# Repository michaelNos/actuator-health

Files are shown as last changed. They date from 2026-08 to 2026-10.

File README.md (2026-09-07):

# Actuator Health Monitoring System

Engineering development repository for a laboratory-scale actuator condition-monitoring system based initially on current measurement and waveform analysis of a low-voltage DC actuator.

Rev-1 is developed **design-first**: the product is specified and baselined at system and subsystem level before physical implementation begins. Implementation and verification then follow the approved engineering documentation rather than completing the design ad hoc on the bench.

## Current project status

The Rev-1 Stage A architecture, subsystem designs, verification plan, and implementation handoff are frozen. **Stage B implementation and bench validation are now in progress.**

Completed Stage B work includes:

- initial DC motor and bench-supply characterization;
- ACS724 current-sensor bring-up;
- low-current DC calibration and linearity verification;
- steady-state motor-current validation;
- oscilloscope measurement-path troubleshooting and controlled noise investigation;
- HANMATEK DOS1102S USB export workflow using BMP, BIN, and CSV;
- reproducible raw-waveform analysis from exported CSV data;
- controlled OFF/ON spectral comparison and repeatability testing;
- first speed-dependent motor-current spectral observation.

The present low-current bench calibration is:

```text
VOUT = 0.46910 + 0.74472 * I
I    = (VOUT - 0.46910) / 0.74472
```

where `VOUT` is in volts and `I` is in amperes.

At the validated 4 V operating point, the calibrated ACS724 reproduced approximately **34.8 mA** while the PSU indicated **35 mA**. This is strong bench agreement, but not a formal accuracy certification because the PSU display is not an independently calibrated current reference.

## Latest dynamic-measurement result

Controlled 1-second CH1 CSV captures were acquired at **10 kS/s** with matched oscilloscope settings. Repeated OFF/ON testing showed a low-frequency component that appears with motor operation and is not comparably present in adjacent OFF captures.

A follow-up operating-point test showed the dominant motor-related component moving with motor supply voltage / speed:

| Motor supply | PSU current | PSU power | Dominant component |
|---:|---:|---:|---:|
| 4.0 V | 34 mA | 0.135 W | ~81 Hz |
| 5.0 V | 35 mA | 0.175 W | ~108 Hz |
| 6.0 V | 36 mA | 0.216 W | ~134 Hz |

This is strong evidence that the feature is associated with the running motor rather than fixed bench interference. Its exact physical mechanism has **not** yet been assigned, and it is **not** accepted as a health or fault signature.

The broadband ACS724 output background remains much larger than the localized motor-related spectral component, so measurement-chain noise characterization remains an active Stage B task.

## Immediate next engineering work

The next controlled verification step is a **same-ground noise-floor capture** using the same oscilloscope acquisition settings as the valid ACS724 CSV measurements. This will quantify how much of the approximately 25 mV RMS-type background originates in the measurement setup itself.

The planned sensor-supply comparison then follows:

```text
bench 5 V -> Arduino 5 V -> bench 5 V
```

with the sensor, probe, grounding, and acquisition configuration held fixed as far as practical.

Only after the dominant background-noise contributors are understood will the project proceed to the designed analog-front-end / anti-alias implementation and full dynamic verification.

The formal Rev-1 diagnostic band remains **DC-10 kHz**. The current 10 kS/s scope CSV captures are suitable for the present low-frequency investigation only; they do not satisfy final full-band verification.

## Project documentation

The `docs/` directory is the authoritative engineering record. The `study/` directory contains supporting learning material, and `analysis/` contains reproducible analysis code.

Key Stage B records currently include:

- [Stage B Implementation Log](docs/15-stage-b-implementation-log.md)
- [ACS724 DC Calibration](docs/16-acs724-dc-calibration.md)
- [ACS724 Motor Validation and Noise Exploration](docs/evidence/acs724-motor-validation-and-noise-2026-09-07.md)
- [ACS724 Raw Waveform Export and Speed-Dependent Spectrum](docs/evidence/acs724-raw-waveform-and-speed-spectrum-2026-09-07.md)
- [`analysis/acs724_raw_csv_fft.py`](analysis/acs724_raw_csv_fft.py) for reproducible DOS1102S CSV analysis

Raw instrument exports are preserved under the relevant `docs/evidence/raw/` folders. Original evidence should remain unchanged; analysis must not silently alter source files.

See the [documentation index](docs/README.md) for the authoritative documentation convention and the complete Rev-1 record.

## Measurement hardware currently in use

- **Current sensor:** Pololu #4048 / ACS724LLCTR-05AU, unidirectional 0-5 A
- **Controller:** Arduino UNO R4 WiFi
- **Oscilloscope:** HANMATEK DOS1102S, 110 MHz, integrated AFG
- **Bench PSU:** Jesverty SPS-3010V
- **Multimeter:** VC830L
- **Test actuator:** low-voltage brushed DC motor used for Stage B bench validation

The stock ACS724 carrier includes a **1 nF FILTER capacitor**, corresponding to approximately **90 kHz** sensor bandwidth. No additional ACS724 FILTER capacitance has been accepted for Rev-1 at this stage.

## Development workflow

Engineering work is controlled through documentation, explicit decisions, measured evidence, and pull requests.

One engineering phase or controlled change is developed on one branch and one pull request. Only explicitly approved engineering decisions are baselined. Values that legitimately depend on hardware, calibration, or measurements remain `TBD` until evidence exists rather than being invented.

The project owner performs the final manual merge.

## Project objective

The goal is not only to measure motor current. The final system is intended to acquire trustworthy actuator-current data, extract meaningful features, detect abnormal behavior, propagate measurement validity, and support repeatable health-monitoring decisions with a documented verification trail.

## Safety scope

Rev-1 is a low-voltage laboratory prototype. Hobby development hardware, breadboards, the Pololu ACS724 carrier, and ordinary oscilloscope probes are not to be connected directly to industrial 400 V three-phase circuits. Future industrial scaling requires appropriately rated isolated sensing and industrial installation practices.

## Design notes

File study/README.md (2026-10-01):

# Study Notes

This directory is the learning notebook for the Actuator Health Monitoring System project.

It is intentionally separate from `docs/`, which remains the authoritative professional engineering record.

## LEARN-001 — Separation of engineering baseline and study notes

**Status:** Accepted

Purchased devices, ICs, relevant modules, and laboratory instruments shall be studied as they become relevant to project development.

Broader educational material shall be maintained separately from the formal engineering phase documentation.

- `docs/` contains approved requirements, design decisions, calculations, tests, results, limitations, verification evidence, and next actions that belong to the engineering baseline.
- `study/` contains deeper device theory, operating principles, datasheet interpretation, terminology, practical lessons, experiments for learning, and Anki-style review material.

Knowledge from `study/` shall enter the formal engineering documentation only when it becomes relevant to an accepted project decision, calculation, test, result, or limitation.

Study notes are therefore educational support material and are not themselves an engineering approval mechanism.

## Study workflow

When a device becomes relevant to the project, study it before relying on it in the design:

`Identify → Read primary documentation → Understand operating principle → Understand important limits/parameters → Perform useful learning experiments → Apply relevant knowledge to the engineering design`

Important terminology may be captured in compact Anki-style form:

**Front:** What is the term or engineering question?  
**Back:** Concise technically correct explanation.

Unknown values remain unknown until verified from primary documentation, calculated, or measured.

## Explain before changing the experiment

Working preference confirmed on 2026-09-13: use short, focused messages and explain each step before asking the user to perform it.

For each measurement or setting change:

1. State the question and the relevant operating principle in plain language.
2. Explain the expected result and what alternatives would mean.
3. Give one concrete action, using the exact instrument, component, pin/net, and units.
4. State what observation to report.
5. Interpret the result before choosing the next action, and document the explanation and evidence in the relevant study note.

Use the existing schematic and confirmed instrument information. Request another photograph only when it resolves a specific missing observation. Keep observed readings, calculations, predictions, and hypotheses explicitly distinguishable. Preserve corrections and mark skipped or pending tests accurately.

Keep chat explanations brief; use the study notes for the fuller explanation, primary sources, and worked examples.

## Study notes

- [`lab-measurement-and-breadboard-notes.md`](lab-measurement-and-breadboard-notes.md) — breadboard connectivity, measurement discipline, instrument cross-checking, ACS724 transfer-function fundamentals, and review questions from Stage B bench work.
- [`acs724-dc-calibration-fundamentals.md`](acs724-dc-calibration-fundamentals.md) — resistor-load design, parallel-current sharing, resistor power, ACS724 sensitivity/offset, linear regression interpretation, voltage-reference mistakes, PSU current limiting, and review questions from the first DC calibration.
- [`acs724-noise-bandwidth-and-fft.md`](acs724-noise-bandwidth-and-fft.md) — oscilloscope signal-path checks, AC/DC coupling, bandwidth/noise trade-offs, control measurements, RMS versus peak-to-peak, FFT center/span, windowing, and lessons from the first motor OFF/ON spectral comparison.

- [`oscilloscope-acquisition-and-triggering.md`](oscilloscope-acquisition-and-triggering.md) — Sample versus Average, triggering, display settings, DC versus AC measurements, and the unresolved CH1 amplitude variation after rewiring.

- [`mcp6022-pinout-and-fixture.md`](mcp6022-pinout-and-fixture.md) — physical pin orientation, all eight pin functions, supply connections, and how the two amplifiers implement the fixture.

- [`sampling-phase-spectrum-transfer-fundamentals-2026-09-18.md`](sampling-phase-spectrum-transfer-fundamentals-2026-09-18.md) — practical calculation of sample interval/rate, Nyquist and record planning, residuals, manual phase measurement, sine/cosine fitting, FFT/harmonics, dB, complex transfer phasors, FILTER corner behavior, scope channel skew, normalized frequency response, and ACS724 dynamic timing terms.

## Initial study queue

The current project hardware provides the initial learning queue. Notes should be added when each item becomes relevant rather than attempting to study everything at once.

- Allegro ACS724 / Pololu #4048 current-sensor carrier
- Arduino UNO R4 WiFi
- Renesas RA4M1 microcontroller
- MCP6022 operational amplifier
- MAX485 RS-485 modules
- MCP2551 CAN transceiver modules
- HANMATEK DOS1102S oscilloscope and function generator
- Jesverty SPS-3010V bench power supply
- relevant passive components, protection parts, wiring, connectors, and measurement techniques as they enter the design

## Relationship to engineering phases

The engineering phase workflow does not change because of this directory.

A study note may contain explanations, examples, or experiments that are useful for learning but are not yet accepted project decisions. Formal phase documents continue to baseline only explicitly approved engineering work.

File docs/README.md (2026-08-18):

# Engineering Documentation

This directory is the authoritative engineering record for the Actuator Health Monitoring System.

## Convention

Each development phase has one numbered Markdown document. Markdown is the source of truth because engineering changes remain readable and reviewable in Git diffs and pull requests. Word/PDF documents may be generated later as deliverables, but they shall not become a competing source of truth.

## DEV-001 — Design-before-implementation workflow

**Status:** Accepted

Rev-1 of the Actuator Health Monitoring System shall be fully specified and baselined at product and subsystem level before physical implementation begins.

The design stage shall establish requirements, architecture, subsystem designs, interfaces, calculations, component selections, calibration strategy, firmware/software architecture, diagnostic strategy, BOM/build information, and verification procedures.

Physical measurements and implementation-dependent results may remain `TBD` during design where they cannot legitimately be known before hardware exists.

After the Rev-1 design baseline is complete, implementation shall proceed from the documented design. Verification shall then populate the planned tests with measured results and identify any necessary deviations or redesign.

### Consequence for phase closure

A design phase does **not** require execution of future hardware tests before it can close. It must instead provide a sufficiently complete design baseline and a defined verification method so later implementation can be performed and checked against the documentation.

Detailed test steps that do not change product design should be consolidated into verification procedures rather than promoted into separate product decisions.

## Rev-1 development stages

### Stage A — Product definition and detailed design

| Phase | Topic | Status |
|---|---|---|
| 1 | System Requirements | Complete / baselined |
| 2 | System Architecture | Complete / baselined |
| 3 | ACS724 Sensor Design and Verification Plan | Design complete / baselined |
| 4 | Measurement-Chain Requirements and Error-Budget Allocation | Design complete / baselined |
| 5 | Analog Front End and Anti-Alias Filter Design | Design complete / baselined |
| 6 | ADC and Deterministic Acquisition Design | Design complete / baselined |
| 7 | MCU Firmware and Signal-Processing Architecture | Design complete / baselined |
| 8 | Diagnostics / Health-Monitoring Logic | Design complete / baselined |
| 9 | Communication Interface Design | Design complete / baselined |
| 10 | Power and Protection Design | Design complete / baselined |
| 11 | Calibration and PC/MATLAB Analysis Design | Design complete / baselined |
| 12 | System Integration, Wiring, BOM and Build Specification | Design complete / ready for PR review |
| 13 | System Verification and Acceptance Plan | Planned |
| 14 | Rev-1 Design Review and Design Freeze | Planned |

### Stage B — Implementation

| Phase | Topic | Status |
|---|---|---|
| 15 | Rev-1 Hardware / Firmware / Software Implementation | Planned after design freeze |

### Stage C — Verification and finalization

| Phase | Topic | Status |
|---|---|---|
| 16 | Subsystem Verification, Calibration and System Validation | Planned after implementation |
| 17 | Final Results, Limitations and Product Documentation | Planned after validation |

The ordering of future design phases may be refined only through an explicit engineering-documentation update; implementation shall not begin merely because an individual subsystem design is available.

## Engineering record rule

Where practical, work remains traceable as:

`Requirement → Architecture → Design → Implementation → Verification → Evidence → PASS/FAIL`

Only explicitly approved decisions are baselined. Unknown values remain `TBD` until calculated, measured, or otherwise justified.

One engineering phase normally uses one branch and one pull request. During design, product decisions are committed as approved; verification details may be consolidated when they are procedural rather than independent design choices.

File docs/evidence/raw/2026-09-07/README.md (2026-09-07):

# Raw DOS1102S evidence inventory — 2026-09-07

Original files captured during the ACS724 USB-export and motor-spectrum experiment:

## Native screenshots
- `bmp_20_002.bmp`
- `bmp_20_003.bmp`
- `bmp_20_004.bmp`

## Native BIN exports
- `data_20_001.bin`
- `data_20_002.bin`
- `data_20_003.bin`
- `data_20_004.bin`
- `data_20_005.bin`

## CSV exports
- `data_20_006.csv` — first CSV; invalid voltage scaling because scope metadata was 10X while physical probe was 1X
- `data_20_007.csv` — corrected 1X exploratory capture; motor state unknown
- `data_20_008.csv` — corrected 1X exploratory capture; motor state unknown
- `data_20_009off.csv` — controlled motor OFF
- `data_20_010on.csv` — controlled motor ON
- `data_20_011off.csv` — repeatability sequence OFF
- `data_20_012on.csv` — repeatability sequence ON
- `data_20_013off.csv` — repeatability sequence OFF
- `data_20_014on.csv` — repeatability sequence ON
- `data_20_015-4v.csv` — motor ON, 4 V, PSU 34 mA / 0.135 W
- `data_20_016-5v.csv` — motor ON, 5 V, PSU 35 mA / 0.175 W
- `data_20_017-6v.csv` — motor ON, 6 V, PSU 36 mA / 0.216 W

005 = A1 OUT, bench
006 = B1 OUT, Arduino
007 = A2 OUT, bench
008 = A1 VCC, bench
009 = B1 VCC, Arduino
010 = A2 VCC, bench
011 = VCC, bandwidth limit OFF
012 = VCC, limit OFF
013 = VCC, 20 MHz limit ON
014 = VCC, limit OFF
015 = OUT, limit 20MHz
016 = OUT, limit 20MHz
017 = OUT, limit 20MHz

The exact original files were also bundled during the documentation session as `acs724_scope_raw_2026-09-07.zip`. Binary/raw file bytes are intentionally not reconstructed from screenshots or derived analysis.

See `docs/evidence/acs724-raw-waveform-and-speed-dependent-spectrum-2026-09-07.md` for validity classification and results, and `analysis/acs724_raw_csv_fft.py` for the reproducible CSV analysis method.

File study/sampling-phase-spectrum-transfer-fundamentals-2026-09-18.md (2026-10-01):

# Sampling, phase, spectrum, transfer function, and ACS724 dynamics — study questions

**Project:** Actuator Health Monitoring System  
**Date:** 2026-09-18  
**Purpose:** Educational note answering the questions raised during Stage B ACS724 dynamic/FILTER validation.

This is a **study note**, not an engineering-baseline approval. Numerical examples from the current bench work are used to explain the concepts. Accepted engineering decisions remain in `docs/`.

The current measurement convention is:

- **CH1:** voltage across the measured reference resistor `R8 = 67 Ω`, used to calculate primary current: `I = V_CH1 / 67 Ω`.
- **CH2:** Pololu #4048 / ACS724 `OUT` voltage relative to circuit ground.
- The temporary MCP6022 fixture creates a **positive-biased periodic current** through the ACS724 primary path.
- Current dynamic work uses coherent extraction of a known excitation frequency from noisy data.

---

## 1. How can I determine Δt, sampling rate, Nyquist frequency, record duration, and captured cycles myself — before running the measurement?

The first job is **not to read Δt from a CSV after the experiment**. The goal is to plan the acquisition from the signal frequency, then use the oscilloscope itself to verify that the selected acquisition actually provides the required sample rate.

### 1.1 What Δt means

`Δt` is the time between two consecutive stored samples:

`sample n ---- Δt ---- sample n+1 ---- Δt ---- sample n+2`

Sample rate and sample interval are reciprocals:

`fs = 1 / Δt`

therefore:

`Δt = 1 / fs`

Examples:

- `fs = 25 kSa/s` → `Δt = 1/25000 = 40 µs`
- `fs = 250 kSa/s` → `Δt = 1/250000 = 4 µs`

So to determine `Δt` yourself, determine the **actual sample rate currently used by the scope**, then take its reciprocal.

### 1.1A Project-specific DOS1102S operating rule — 10K depth is fixed

For the current Actuator Health Monitoring System bench workflow, **record depth is fixed at 10K points**. The operator should not be instructed to “set Δt”. The oscilloscope screen control available before acquisition is the horizontal main timebase:

`M: ... ms/div`

From repeated CSV captures with this exact DOS1102S setup, the stored 10K record spans approximately:

`Trecord ≈ 20 × M`

where `M` is the displayed main timebase in seconds per division.

Therefore, with `N = 10000` fixed:

`Δt ≈ Trecord/N = (20 × M)/10000`

For the convenient units used on the screen:

`Δt [µs] ≈ 2 × M [ms/div]`

and equivalently:

`fs [kSa/s] ≈ 500 / M [ms/div]`

Examples established on this bench:

| DOS1102S screen setting | Fixed depth | Approx. stored Δt | Approx. sample rate |
| --- | ---: | ---: | ---: |
| `M: 20 ms/div` | 10K | `40 µs` | `25 kSa/s` |
| `M: 5 ms/div` | 10K | `10 µs` | `100 kSa/s` |
| `M: 2 ms/div` | 10K | `4 µs` | `250 kSa/s` |

This is an **empirical project-specific rule for the current DOS1102S configuration**, not a universal oscilloscope law. It comes from the actual exported records.

#### Future bench-instruction rule

For this project:

- keep **Depth = 10K** unless an explicit engineering reason is approved to change it;
- when planning a capture, give the operator the **screen setting** to use, for example `M: 2 ms/div`;
- do **not** ask the operator to “set Δt = 4 µs” because Δt is not the direct front-panel setting;
- Δt may still be calculated in the explanation, but the actionable instruction must be the DOS1102S `M: ... ms/div` setting;
- after acquisition, verify the actual CSV timestamps/sample interval as a check.

For the current 10 kHz / ~25-samples-per-cycle requirement, the bench instruction is therefore:

`Set M: 2 ms/div, Depth: 10K.`

not:

`Set Δt = 4 µs.`

### 1.2 Method A — read the current sample rate from the oscilloscope

If the scope shows the current acquisition sample rate, use that value directly.

For example, if the scope reports:

`250 kSa/s`

then:

`Δt = 1/(250000) = 4 µs`

If it reports:

`25 kSa/s`

then:

`Δt = 40 µs`

Do not confuse the instrument's advertised **maximum** sample rate with the sample rate of the current acquisition. The scope may reduce the current sample rate when a longer time window is selected.

### 1.3 Method B — use record length and the actual stored acquisition duration

If you know:

- number of stored samples `N`;
- total duration represented by those stored samples `Trecord`;

then approximately:

`Δt ≈ Trecord / N`

and:

`fs ≈ N / Trecord`

More exactly, if the first and last stored samples are both included:

`Δt = (t_last - t_first)/(N - 1)`

For acquisition planning with 10000 points, the difference between `N` and `N-1` is very small.

Example:

`N = 10000`

`Trecord = 40 ms`

then:

`Δt ≈ 0.040/10000 = 4 µs`

and:

`fs ≈ 250 kSa/s`

### 1.4 Method C — inspect adjacent stored points on the stopped scope display

If the scope allows you to show individual sample dots and zoom deeply into a stopped record:

1. stop acquisition;
2. display/zoom until individual stored points are visible;
3. use time cursors between two adjacent points;
4. the horizontal time difference is approximately `Δt`.

This is the most direct physical interpretation of sample interval.

### 1.5 Why the visible grid alone is not enough — and what we now know for this scope

A generic oscilloscope rule such as:

`Δt = (10 horizontal divisions × time/div)/record_length`

must **not** be assumed without verification. The visible grid width and the complete stored-memory span are not necessarily the same.

For this DOS1102S bench configuration, however, repeated exported 10K records have established an empirical relationship:

`Trecord ≈ 20 × M`

not `10 × M`.

Therefore, while `M` alone is not universally enough on an arbitrary oscilloscope, it **is operationally usable here because the 10K depth is fixed and the 20 × M record-span relationship has been verified from our own CSVs**.

The project workflow is now:

`signal requirement → choose required sampling quality → convert to DOS1102S M setting → acquire at fixed 10K → verify CSV Δt afterward`

The operator-facing instruction should stop at the actual screen control:

`M: ... ms/div`

### 1.6 How to choose Δt before pressing RUN

Start from the signal frequency.

If the target signal frequency is `fsig`, then its period is:

`Tsig = 1/fsig`

Choose how many samples you want per cycle. For the present phase/waveform work, approximately **20–25 or more samples per cycle** is a useful engineering target, not a universal law.

Then:

`Δt_wanted = Tsig / samples_per_cycle`

and equivalently:

`fs_target = samples_per_cycle × fsig`

#### Example: design the 10 kHz acquisition before measuring

Target:

`fsig = 10 kHz`

Signal period:

`Tsig = 1/10000 = 100 µs`

Choose:

`25 samples/cycle`

Required sample interval:

`Δt_wanted = 100 µs / 25 = 4 µs`

Required sample rate:

`fs_target = 1/4 µs = 250 kSa/s`

So before touching RUN, the target is already known:

`10 kHz → 100 µs/cycle → 4 µs/sample → 250 kSa/s → 25 samples/cycle`

Now set the oscilloscope acquisition/timebase so that the **actual current sample rate** is approximately 250 kSa/s or faster.

### 1.7 Then determine record duration and captured cycles

If the scope stores `N = 10000` points at:

`fs = 250 kSa/s`

then:

`Trecord = N/fs = 10000/250000 = 40 ms`

At 10 kHz:

`cycles = Trecord × fsig = 0.040 × 10000 = 400 cycles`

So the complete designed acquisition is:

`10 kHz signal`

`→ 100 µs period`

`→ 4 µs desired sample spacing`

`→ 250 kSa/s sample rate`

`→ 25 samples/cycle`

`→ 10000 samples`

`→ 40 ms record`

`→ 400 captured cycles`

#### Same calculation for 1 kHz

At:

`fsig = 1 kHz`

period:

`Tsig = 1 ms`

For the same 25 samples/cycle:

`Δt_wanted = 1 ms/25 = 40 µs`

`fs_target = 25 kSa/s`

With 10000 samples:

`Trecord = 10000/25000 = 0.4 s`

Captured cycles:

`0.4 × 1000 = 400`

This is why preserving 25 samples/cycle requires a sample interval ten times shorter when the signal frequency becomes ten times higher:

- 1 kHz → `Δt = 40 µs`
- 10 kHz → `Δt = 4 µs`

### 1.8 After the acquisition, verify what actually happened

After the capture, verify that the scope actually used the intended settings:

1. actual sample rate;
2. record length;
3. actual record duration;
4. resulting samples/cycle;
5. resulting captured-cycle count.

CSV timestamps can be used later as an independent verification, but they are **not required to understand or plan Δt**.

### 1.9 From Δt to Nyquist

Once `Δt` is known:

`fs = 1/Δt`

and:

`fNyquist = fs/2`

Example with `Δt = 4 µs`:

`fs = 250 kSa/s`

`fNyquist = 125 kHz`

For a 10 kHz signal, this gives:

`samples_per_cycle = 250/10 = 25`

This is comfortably above the theoretical two-samples-per-cycle Nyquist boundary and is much more suitable for waveform and phase measurements.

### 1.10 Bench calculation checklist

Before running a periodic test, write down:

1. `fsig = ?`
2. `Tsig = 1/fsig = ?`
3. desired samples/cycle = ?
4. `Δt_wanted = Tsig/samples_per_cycle = ?`
5. `fs_target = 1/Δt_wanted = ?`
6. record length `N = ?`
7. `Trecord = N/fs = ?`
8. captured cycles `= Trecord × fsig = ?`
9. Nyquist `= fs/2 = ?`
10. verify the actual `fs` on the oscilloscope before accepting the measurement.

That is the manual acquisition-design process to use even if ChatGPT does not exist.

### 1.11 How do I decide how many samples per cycle I want?

There is no single correct number. The choice depends on **what you want to learn from the waveform**.

Nyquist gives only the theoretical minimum:

`fs > 2 * fsig`

which means a little more than two samples per cycle for an ideally band-limited sinusoid. That may be enough to avoid the most basic aliasing condition, but it is **not a good engineering target** for measuring amplitude, phase, waveform shape, or harmonics.

A practical way to think about it is:

| Measurement goal | Practical starting point |
| --- | ---: |
| Detect that a periodic signal exists | about 5–10 samples/cycle |
| Reasonable amplitude estimate | about 10–20 samples/cycle |
| Amplitude and phase | about **20–25+ samples/cycle** |
| Waveform shape / distortion | about 25–50+ samples/cycle |
| Higher harmonics / fast edges | often much higher |

These are engineering guidelines, not mathematical laws.

For the present ACS724 transfer-function work we care about:

- coherent amplitude;
- relative phase;
- distortion/harmonics;
- repeatable fitting;
- enough captured cycles for noise rejection.

Therefore **25 samples/cycle** is a useful working target.

#### Example at 10 kHz

Signal period:

`Tsig = 1/10000 = 100 µs`

Choose:

`25 samples/cycle`

Then:

`Δt = 100 µs / 25 = 4 µs`

and:

`fs = 1/4 µs = 250 kSa/s`

With a 10000-point record:

`Trecord = 10000/250000 = 40 ms`

Captured cycles:

`40 ms * 10 kHz = 400 cycles`

So this one choice gives both:

- 25 samples/cycle for waveform and phase resolution;
- 400 captured cycles for coherent averaging/fitting.

#### The trade-off with fixed record memory

If record length is fixed, increasing samples per cycle increases sample rate and therefore shortens total observation time.

At 10 kHz with 10000 stored points:

**5 samples/cycle**

`fs = 50 kSa/s`

`Trecord = 200 ms`

`cycles = 2000`

This gives many cycles, but poor representation of each cycle.

**25 samples/cycle**

`fs = 250 kSa/s`

`Trecord = 40 ms`

`cycles = 400`

This is a good compromise for our amplitude/phase work.

**100 samples/cycle**

`fs = 1 MSa/s`

`Trecord = 10 ms`

`cycles = 100`

This gives excellent detail within each cycle, but a much shorter observation window.

Therefore the acquisition-design trade-off is:

`more samples/cycle ↔ shorter record`

when record memory is fixed.

The practical decision sequence is:

`measurement goal → choose samples/cycle → calculate fs → calculate Δt → calculate Trecord → check captured-cycle count`

For the current ACS724 work:

`amplitude + phase + coherent extraction → about 25 samples/cycle`

That is why 25 samples/cycle was selected for the 1 kHz and 10 kHz dynamic measurements.

---

## 2. Is residual noise equal to ACS724 OUT minus IP−? Should CH1 and CH2 be equal?

**No. This is the most important correction in this note.**

CH1 and CH2 are not two measurements of the same physical quantity.

CH1 is the voltage across R8:

`V_CH1 = I_primary * R8`

CH2 is the sensor output:

`V_CH2 ≈ VZERO + S(f) * I_primary`

where:

- `VZERO` is the ACS724 zero-current output;
- `S(f)` is its frequency-dependent sensitivity in V/A.

Therefore CH1 and CH2 should **not** normally be equal in volts.

For example, if the current variation is 7 mApp:

`V_CH1,pp = 0.007 * 67 ≈ 0.469 Vpp`

With approximately 0.8 V/A sensor sensitivity:

`V_CH2,pp ≈ 0.007 * 0.8 = 5.6 mVpp`

Those are intentionally very different voltages.

### What residual means

For CH2 we fit:

`Vfit(t) = VDC + Vtarget(t)`

Then:

`e(t) = V_CH2,measured(t) - Vfit(t)`

So residual is **CH2 minus its own modeled DC + wanted coherent component**.

It is not:

`CH2 - CH1`

The residual can contain noise, harmonics, interference, drift, quantization, and any other waveform content not included in the model.

---

## 3. What is apparent transfer? Is it power?

**Apparent transfer** means:

> The input-to-output relationship that our measurement setup appears to show, before we have proven that every part of that relationship belongs only to the ACS724 itself.

In this experiment, the **input** is the actual AC current through the ACS724 primary conductor. CH1 measures the voltage across R8, so:

`I_primary(f) = V_CH1(f) / 67 Ω`

The **output** is the coherent AC component measured at ACS724 OUT with CH2:

`V_OUT(f)`

Therefore:

`H_apparent(f) = V_OUT(f) / I_primary(f)`

Its unit is:

`V/A`

This answers the practical question:

> For every ampere of current variation at this frequency, how many volts of output variation do we observe?

Example:

`Ipp = 6.8 mA`

`V_OUT,pp = 5.8 mV`

then:

`H_apparent = 5.8 mV / 6.8 mA ≈ 0.85 V/A`

Meaning:

> At that frequency, the complete measured system appears to convert current changes into voltage changes at about 0.85 volts per ampere.

### Why it is called a transfer

A transfer function describes how an input is transferred to an output.

For our measurement:

`input = primary current`

`output = ACS724 OUT voltage`

So the transfer describes both:

- how much the amplitude changes from input to output;
- how much phase shift appears between input and output.

It is therefore more than a simple scalar gain when phase matters.

### Why we call it apparent

The measured value is not automatically the exact intrinsic sensitivity of the ACS724 itself.

The observed transfer can still contain contributions from:

- the ACS724 Hall sensing element;
- internal amplifier and compensation dynamics;
- the FILTER-pin network;
- probe/scope frequency response;
- CH1↔CH2 timing skew;
- noise;
- finite record length;
- coherent-fit uncertainty.

Conceptually:

`H_measured = H_physical_sensor+filter × H_measurement_system`

This is why the word **apparent** is useful during validation: it means “this is what the experiment currently makes us observe.”

As controls identify and remove measurement artifacts, the estimate can move closer to the physical sensor/filter transfer.

### Example from the current project

At 10 kHz, the raw measured phase was about:

`-74°`

The same-node control showed that approximately:

`-14.5°`

came from a one-sample CH1↔CH2 acquisition/export offset.

Therefore the original `-74°` phase was an **apparent phase transfer** of the complete measured chain, not purely the ACS724.

After correcting the known timing artifact, the estimate moved closer to the physical response:

`≈ -60°`

This does **not** prove that every remaining degree of phase lag belongs only to the bare ACS724; the physical sensor, FILTER network, and any remaining measurement-chain dynamics still contribute.

### Apparent transfer is not power

No power quantity is being calculated here.

Power would have units such as watts:

`W = V × A`

Our transfer has units:

`V/A`

So this is a frequency-dependent sensitivity/gain, not electrical power.

### Magnitude and phase form

For frequency-domain work, transfer is often written as a complex phasor:

`H(f) = |H(f)| ∠ φ(f)`

For example:

`H(1 kHz) ≈ 0.85 ∠ -18° V/A`

means:

- the measured magnitude is about `0.85 V/A`;
- the output sinusoid lags the current-reference sinusoid by about `18°`.

So the most useful summary is:

`transfer = input-output relationship`

`apparent transfer = the input-output relationship currently observed by the complete experiment`

That distinction is important until the measurement chain has been fully characterized.

---

## 4. How can I determine phase without ChatGPT?

For two clean periodic signals of the same frequency, use the oscilloscope's time cursors.

1. Measure the period `T`.
2. Choose corresponding points on CH1 and CH2, preferably rising zero crossings or equivalent peaks.
3. Measure their time displacement `Δt_phase`.
4. Convert to phase:

   `phase_deg = 360° * Δt_phase / T`

If CH2 occurs later than CH1, CH2 **lags**, so with our convention its phase is negative.

Example at 10 kHz:

`T = 1/10000 = 100 µs`

If CH2 occurs 16 µs after CH1:

`φ = -360 * 16/100 = -57.6°`

For noisy CH2, a single cursor crossing can be inaccurate. The coherent sine/cosine fit uses all samples and is therefore more robust, but the cursor method is the direct manual method.

The DOS1102S specification also lists automatic `Phase A→B` and delay measurements, but any automatic result should be checked against known controls when millivolt-level noisy signals are involved.

---

## 5. At 1 kHz or 10 kHz, are we sending AC current? Why does current change faster or slower?

The AFG generates a periodic voltage, normally a sine.

In our temporary fixture the MCP6022 shifts it so the current through the ACS724 remains **positive**. Therefore the current is best described as:

`i(t) = IDC + IAC*sin(2πft + φ)`

So it contains:

- a DC bias;
- an AC variation/ripple.

It is **not** a bipolar current that necessarily reverses direction every half-cycle.

Frequency tells us how fast the repeating change happens:

- 100 Hz → period = 10 ms
- 1 kHz → period = 1 ms
- 10 kHz → period = 100 µs

At 10 kHz the current completes 10000 oscillations each second. At 100 Hz it completes only 100.

The current changes because the driving voltage changes. In the temporary mostly resistive primary path, current follows the drive relatively quickly. In a strongly inductive load, inductance would oppose rapid current change according to `V = L di/dt`.

Also, this is not an **impulse**. An impulse is a short transient event. We are applying a periodic sinusoidal stimulus.

---

## 6. How can I calculate spectrum and harmonics manually on paper?

If you want to calculate the spectrum yourself from measured samples, without using the oscilloscope FFT function, you are doing a small **DFT/Fourier calculation by hand**.

For this project you usually do not need to calculate the entire spectrum. If the AFG is set to `1 kHz`, you can calculate selected components directly:

`1 kHz, 2 kHz, 3 kHz, 4 kHz, ...`

one harmonic at a time.

### 6.1 Start with measured samples

Suppose you have `N` equally spaced samples:

`x0, x1, x2, ..., x(N-1)`

with sample interval:

`Δt`

Sample `n` occurred at:

`tn = n * Δt`

First calculate the DC/mean value:

`VDC = (1/N) * Σ x_n`

Then remove it:

`y_n = x_n - VDC`

Now `y_n` contains only the varying part of the waveform.

### 6.2 Ask whether the waveform contains a chosen frequency

Choose a frequency `f`.

For every sample calculate:

`θ_n = 2π f t_n`

Then calculate the sine projection:

`S_f = (2/N) * Σ [y_n * sin(θ_n)]`

and the cosine projection:

`C_f = (2/N) * Σ [y_n * cos(θ_n)]`

These two sums answer:

> How much of the measured waveform points in the sine direction and how much points in the cosine direction at frequency f?

From them calculate the peak amplitude:

`A_pk = sqrt(S_f^2 + C_f^2)`

and peak-to-peak amplitude:

`A_pp = 2 * A_pk`

Using the phase convention adopted in this project:

`φ = atan2(C_f, S_f)`

This is the hand-calculation equivalent of extracting one Fourier component.

### 6.3 Small paper example

Take eight equally spaced samples of one ideal sine period:

| n | angle | measured x_n |
| ---: | ---: | ---: |
| 0 | 0° | 0 |
| 1 | 45° | 0.707 |
| 2 | 90° | 1 |
| 3 | 135° | 0.707 |
| 4 | 180° | 0 |
| 5 | 225° | -0.707 |
| 6 | 270° | -1 |
| 7 | 315° | -0.707 |

The mean is:

`VDC = 0`

For the fundamental, multiply every measured sample by the sine at the same angle:

`x_n * sin(θ_n)`

The products are approximately:

`0, 0.5, 1, 0.5, 0, 0.5, 1, 0.5`

Sum:

`Σ x_n sin(θ_n) = 4`

Therefore:

`S_1 = (2/8) * 4 = 1`

Now do the cosine projection:

`C_1 = (2/8) * Σ [x_n cos(θ_n)]`

For this ideal sine the positive and negative cosine contributions cancel:

`C_1 = 0`

Therefore:

`A_pk = sqrt(1^2 + 0^2) = 1`

and:

`A_pp = 2 V`

Phase:

`φ = atan2(0,1) = 0°`

So the manual calculation reconstructs the original sine:

`1 Vpk, 2 Vpp, 0°`

### 6.4 Calculate a harmonic using the same samples

To calculate the third harmonic, use the **same measured samples**, but test frequency:

`f = 3 f0`

Then:

`S_3 = (2/N) * Σ [y_n sin(2π * 3f0 * t_n)]`

`C_3 = (2/N) * Σ [y_n cos(2π * 3f0 * t_n)]`

and:

`A_3,pk = sqrt(S_3^2 + C_3^2)`

For the ideal sine above, those terms cancel, so:

`A_3 ≈ 0`

because the waveform contains no third harmonic.

If a measured distorted waveform gave:

`A_1 = 1.00 V`

`A_2 = 0.02 V`

`A_3 = 0.10 V`

`A_4 = 0.01 V`

then the waveform would contain a strong fundamental and a noticeable third harmonic.

### 6.5 How this becomes a spectrum

Repeat the same calculation at many frequencies.

For harmonics:

`f1 = f0`

`f2 = 2f0`

`f3 = 3f0`

and so on.

Then plot:

- horizontal axis = frequency;
- vertical axis = calculated amplitude.

That plotted set of amplitudes is the spectrum.

### 6.6 Frequency bins

For a full DFT, the natural bin spacing is:

`Δf = fs/N`

Because:

`Trecord = N/fs`

we can also write:

`Δf = 1/Trecord`

Example:

`Trecord = 40 ms`

then:

`Δf = 1/0.040 = 25 Hz`

So the DFT bins occur at:

`0, 25, 50, 75, ... Hz`

A 10 kHz component corresponds to:

`k = 10000/25 = 400`

So the 10 kHz spectral component asks:

> How strongly do the measured samples correlate with a 10 kHz sine and a 10 kHz cosine?

### 6.7 The physical idea behind the calculation

For each frequency of interest:

1. generate the corresponding sine values;
2. multiply the measured waveform by those sine values and sum;
3. generate the corresponding cosine values;
4. multiply the measured waveform by those cosine values and sum;
5. combine the two results into magnitude and phase.

If the products mostly cancel:

`little component at that frequency`

If they reinforce:

`strong component at that frequency`

The FFT performs essentially this Fourier decomposition very efficiently for many frequencies at once.

For learning on paper, do **not** start with 10000 samples. Use perhaps 8 or 16 samples of a simple waveform and calculate:

- DC;
- fundamental;
- second harmonic;
- third harmonic.

Once those calculations are clear, the FFT is no longer a black box.

---

## 7. If the fundamental is highest and harmonics are much smaller, is the fundamental the wanted result and the rest just noise?

For the present **transfer measurement at a commanded frequency**, the fundamental is the main wanted component.

But harmonics are **not automatically noise**.

A harmonic is a deterministic component at an integer multiple of the fundamental. It can be caused by:

- waveform distortion;
- nonlinearity;
- clipping;
- asymmetry;
- the stimulus generator/fixture;
- the sensor or other circuitry.

Random/broadband noise is different: it is not locked to exact integer multiples in the same deterministic way.

So:

- for `H(1 kHz)`, use the coherent 1 kHz component;
- do not add 3 kHz or 5 kHz into the 1 kHz gain;
- but keep harmonics as diagnostic information because they can reveal distortion or later become health-monitoring features.

The third harmonic in CH1 during our tests was therefore **unmodeled residual content**, but not necessarily random noise.

---

## 8. Why does filtering increase phase lag?

Consider a first-order RC low-pass:

`H(jω) = 1 / (1 + jωRC)`

Its phase is:

`φ = -atan(ωRC)`

A capacitor must charge and discharge. It cannot reproduce rapid input changes instantaneously. As frequency increases, the output waveform increasingly trails the input waveform.

At very low frequency:

`ωRC << 1 → φ ≈ 0°`

At the corner frequency:

`ωRC = 1 → φ = -45°`

Far above the corner:

`ωRC >> 1 → φ approaches -90°`

The lag is not an arbitrary penalty added by mathematics; it is the time-domain consequence of energy storage in the capacitor.

---

## 9. What does “close to Nyquist” mean?

For sample rate `fs`, Nyquist frequency is:

`fN = fs/2`

A sinusoid at Nyquist has only two samples per cycle in the ideal limiting case.

Our old 10 kHz acquisition used:

`fs = 25 kSa/s`

Therefore:

`fN = 12.5 kHz`

and:

`samples_per_cycle = 25/10 = 2.5`

So 10 kHz was very close to the theoretical sampling limit.

It was technically below Nyquist, but there was very little margin. Harmonics above 12.5 kHz could alias into lower frequencies, and waveform/phase interpretation became fragile.

After changing acquisition:

`fs = 250 kSa/s`

At 10 kHz:

`samples_per_cycle = 25`

and Nyquist is 125 kHz. That is much healthier for quantitative work.

Nyquist is a mathematical minimum for reconstructing an ideally band-limited signal, **not a recommendation to measure real analog waveforms with only two or three points per cycle**.

---

## 10. Are we measuring OUT and IP− to calculate residual noise?

No.

We measure them simultaneously for two different purposes:

- CH1 at IP−/R8 gives the primary-current reference.
- CH2 at ACS724 OUT gives the sensor response.

We calculate the transfer:

`H(f) = V_CH2(f) / (V_CH1(f)/R8)`

Residual is calculated separately from one channel after fitting its model.

For CH2:

`e_CH2(t) = V_CH2(t) - [VDC + fitted_target_sine(t)]`

For CH1 we can calculate a separate CH1 residual in the same way.

CH1 is not subtracted from CH2 to obtain noise.

---

## 11. How can I determine VDC manually from an AC-varying signal?

If the scope uses DC coupling, the simplest definition is the time average:

`VDC = (1/N) * Σ v[n]`

On the scope, use a **Mean/Average** voltage measurement if available.

For a clean symmetric sine with no distortion:

`VDC ≈ (Vmax + Vmin)/2`

Example:

`Vmax = 0.506 V`

`Vmin = 0.494 V`

then:

`VDC ≈ 0.500 V`

For a distorted/noisy waveform, the arithmetic mean over many complete cycles is better than midpoint-of-extremes because Vmax and Vmin are sensitive to noise spikes.

---

## 12. How do I understand sine and cosine from the AFG?

The AFG normally generates **one sinusoid**. We are not physically generating a separate sine and cosine.

Mathematically:

`sin(ωt)`

and:

`cos(ωt)`

have the same shape and frequency; cosine is simply sine shifted by 90°:

`cos(ωt) = sin(ωt + 90°)`

Our analysis writes:

`A sin(ωt) + B cos(ωt)`

because that combination can represent a sine of **any phase**:

`C sin(ωt + φ)`

with:

`C = sqrt(A² + B²)`

`φ = atan2(B,A)`

The sine/cosine pair is therefore an analysis coordinate system. The AFG still generates one periodic waveform.

---

## 13. What does −0.49 dB represent?

The earlier `-0.49 dB` number represented an **amplitude ratio**, not absolute voltage and not directly power.

For amplitudes:

`dB = 20 log10(A2/A1)`

A value of `-0.49 dB` corresponds to:

`A2/A1 = 10^(-0.49/20) ≈ 0.945`

So the second amplitude is about **94.5%** of the reference amplitude: approximately 5.5% lower.

Negative dB means attenuation relative to the chosen reference.

That `-0.49 dB` was from the first 10 kHz result compared with the 1 kHz estimate. It was **not the final multi-run estimate**. The later complex-average comparison gave approximately `-0.70 dB`.

---

## 14. What is a complex transfer phasor?

At one frequency, a sinusoid can be represented by:

- magnitude;
- phase.

A phasor stores both together.

For the transfer:

`H(f) = Vout_phasor / Iin_phasor`

It can be written as:

`H = a + jb`

or:

`H = |H| ∠ φ`

Example:

`H(10 kHz) ≈ 0.784 ∠ -59.9° V/A`

means:

- magnitude: about 0.784 V/A;
- output lags the current reference by about 59.9° under the corrected measurement convention.

Complex averaging is useful because it averages the in-phase and quadrature information together. Simply averaging magnitudes would ignore whether individual estimates point in different phase directions.

---

## 15. Does the ACS724 FILTER allow only signals below 15.5 kHz to pass?

No.

The approximately 15.5 kHz value was our estimated **corner frequency** for the FILTER-pin RC network using:

`RF ≈ 1.8 kΩ`

and total capacitance approximately:

`C ≈ 1 nF + 4.7 nF = 5.7 nF`

Then:

`fc = 1/(2πRFC) ≈ 15.5 kHz`

A low-pass filter is not a brick wall.

At `fc` a first-order low-pass has magnitude:

`1/sqrt(2) ≈ 0.707`

which is `-3.01 dB`.

Signals above `fc` still pass, but with progressively greater attenuation and phase lag. Far above `fc`, a first-order pole approaches a -20 dB/decade magnitude slope.

Also, 15.5 kHz is not the ACS724's entire internal bandwidth. It is an estimate for the external FILTER capacitor acting with the device's internal FILTER resistance. Allegro specifies the unfiltered ACS724 analog bandwidth around 120 kHz and provides the FILTER pin so the user can trade bandwidth for lower noise.

---

## 16. If CH1 and CH2 measure the same node, can phase still be different? Why?

Electrically, if both probes measure exactly the same physical node relative to the same ground at the same time, the true phase difference should be approximately:

`0°`

So if CH1 and CH2 are on the same node, a measured phase difference is not expected to come from the circuit itself.

### Why does a “sample” exist at all?

A digital oscilloscope does not store a perfectly continuous waveform.

Instead, it measures voltage at discrete instants and stores a sequence such as:

`V[0], V[1], V[2], V[3], ...`

The time between neighboring stored points is the sample interval:

`Δt`

For example, if:

`Δt = 4 µs`

then the stored waveform corresponds conceptually to measurements at:

`0 µs, 4 µs, 8 µs, 12 µs, ...`

That is what one **sample step** means.

### What did the same-node control reveal?

In our same-node experiment, both probes were physically connected to the same R8 signal node, so the electrical phase difference should have been approximately zero.

But the exported waveforms behaved approximately like:

`CH1[n] ≈ CH2[n+1]`

rather than:

`CH1[n] ≈ CH2[n]`

So CH2 appeared delayed by approximately **one stored sample** relative to CH1.

At 10 kHz:

`Δt = 4 µs`

and one signal period is:

`T = 100 µs`

Therefore one sample corresponds to:

`360° * 4/100 = 14.4°`

At 1 kHz:

`Δt = 40 µs`

and:

`T = 1 ms`

so again:

`360° * 40/1000 = 14.4°`

This matched the approximately `-14.5°` apparent phase difference observed in the same-node controls.

When CH2 was advanced by one stored sample in analysis, the same-node phase difference fell to approximately zero.

### Does this mean the circuit created an extra sample?

No.

The “extra sample” is not a physical electrical event in the ACS724 circuit.

It is an observed timing/alignment difference between how the two channels appeared in the stored/exported digital data.

### Why does this one-sample offset exist?

The exact internal cause is **not established**.

Possible mechanisms in a digital oscilloscope can include:

- channels being digitized or processed sequentially rather than perfectly simultaneously;
- channel-specific ADC or digital-pipeline delay;
- memory alignment;
- export/CSV alignment;
- firmware processing.

However, none of those mechanisms has been proven for this DOS1102S.

The accepted experimental statement is therefore only:

> When both probes measured the same physical signal, the exported CH2 waveform appeared approximately one stored sample behind CH1.

Do not replace that measured fact with an invented internal explanation.

### What this means for future phase measurements

For same-node measurements:

`true electrical phase ≈ 0°`

For CH1-on-R8 and CH2-on-ACS-OUT measurements, additional phase can be physically real because the ACS724 and its filtering have dynamics.

Therefore:

- a same-node phase difference is evidence of measurement-chain timing skew;
- a current-reference-to-sensor-output phase difference can contain both measurement-chain skew and real sensor/filter dynamics.

The same-node control lets us estimate and correct the known channel-alignment artifact before interpreting the physical phase response.

---

## 17. What does H(10k)/H(1k) tell us? What does a ratio generally tell us?

A ratio compares one quantity with another reference.

If:

`R = A2/A1`

then:

- `R = 1`: equal;
- `R < 1`: A2 is smaller;
- `R > 1`: A2 is larger.

For frequency response, use the **complex ratio**:

`Hnorm = H(10 kHz) / H(1 kHz)`

Magnitude:

`|Hnorm| = |H10| / |H1|`

Phase:

`φnorm = φ10 - φ1`

Using the corrected current estimates:

`|H1| ≈ 0.850 V/A`

`|H10| ≈ 0.784 V/A`

Therefore:

`|H10/H1| = 0.784/0.850 ≈ 0.922`

In dB:

`20 log10(0.922) ≈ -0.70 dB`

With phases approximately:

`φ1 = -18.18°`

`φ10 = -59.87°`

then:

`Δφ = -59.87 - (-18.18) ≈ -41.69°`

This normalized ratio is useful because constant absolute sensitivity factors largely cancel. It tells us **how the system changes with frequency**, which is what a frequency-response measurement is meant to show.

---

## 18. How are propagation delay, response time, and rise time calculated?

These are normally **measured from a step response**, not derived from one universal formula.

According to the ACS724 datasheet definitions:

### Propagation delay, tpd

Measure the time between:

- input current reaching 20% of its final step value;
- sensor output reaching 20% of its corresponding final change.

`tpd = t(output 20%) - t(input 20%)`

### Response time, tRESPONSE

Measure the time between:

- input current reaching 90% of its final value;
- sensor output reaching 90% of its corresponding final value.

`tRESPONSE = t(output 90%) - t(input 90%)`

### Rise time, tr

This belongs to the output waveform itself:

`tr = t(output 90%) - t(output 10%)`

For a simple first-order system:

`tr(10–90%) ≈ 2.197τ`

and approximately:

`fc ≈ 0.35/tr`

But the actual ACS724 is more complex than one ideal RC pole, so use datasheet definitions or measured step data for the real device.

Do not confuse these three quantities:

- propagation delay asks **when the output starts following relative to the input**;
- rise time asks **how long the output takes to travel from 10% to 90%**;
- response time compares the input's 90% time with the output's 90% time.

Primary source: Allegro ACS724 datasheet, section “Response Characteristics Definitions and Performance Data”.

---

## 19. Why does RC = f/fc?

It does **not**.

The correct dimensionless expression is:

`ωRC = f/fc`

Derivation:

`fc = 1/(2πRC)`

and:

`ω = 2πf`

Therefore:

`ωRC = (2πf)RC`

From the corner-frequency equation:

`2πRC = 1/fc`

so:

`ωRC = f/fc`

This matters because:

- `RC` has units of seconds;
- `f/fc` has no units.

They cannot be equal by themselves.

The low-pass magnitude can therefore be written either as:

`|H| = 1/sqrt(1+(ωRC)²)`

or:

`|H| = 1/sqrt(1+(f/fc)²)`

and phase as:

`φ = -atan(ωRC) = -atan(f/fc)`

---

## 20. Why does delay contribute to phase shift?

A time delay means the output waveform is shifted to the right in time:

`y(t) = x(t - td)`

For a sine:

`x(t) = sin(2πft)`

then:

`y(t) = sin[2πf(t-td)]`

Expand:

`y(t) = sin(2πft - 2πf td)`

So the phase shift caused by pure delay is:

`φ = -2πf td` radians

or:

`φ = -360° * f * td`

This explains why the same physical delay creates more phase shift at higher frequency.

Example for `td = 2 µs`:

At 1 kHz:

`φ = -360 * 1000 * 2e-6 = -0.72°`

At 10 kHz:

`φ = -7.2°`

The time delay stayed 2 µs, but the 10 kHz period is ten times shorter, so 2 µs occupies ten times more of one cycle.

This is why sensor propagation delay, filter dynamics, probe/channel skew, and digital sample offset all matter in phase measurements.

---

## Compact self-check

Before any future frequency-response capture, be able to answer these without software assistance:

1. What is the target signal frequency and period?
2. What sample rate will the selected acquisition produce?
3. How many samples per cycle will that give?
4. What is Nyquist frequency?
5. How long is the record?
6. How many cycles will be captured?
7. Which node represents current and which represents sensor output?
8. What gain unit should the transfer have?
9. Is a measured phase difference physical or could it be channel timing skew?
10. Is a spectral line a harmonic, interference component, or broadband noise?

If those ten questions are clear before the capture, the measurement is much easier to interpret correctly afterward.

## Primary references

- Allegro MicroSystems, **ACS724 datasheet**: https://www.allegromicro.com/-/media/files/datasheets/acs724-datasheet.ashx
- Pololu, **ACS724 Current Sensor Carrier -5A to +5A, 5V (item #4048)**: https://www.pololu.com/product/4048
- HANMATEK, **DOS1102S product/manual center**: https://hanmatek.com/en-eu/pages/manuals-center
- Related project notes:
  - [Oscilloscope acquisition and triggering](oscilloscope-acquisition-and-triggering.md)
  - [Signal-analysis concepts used in ACS724 dynamic validation](signal-analysis-concepts-for-acs724-dynamic-validation-2026-09-11.md)
  - [ACS724 noise, bandwidth, and FFT](acs724-noise-bandwidth-and-fft.md)

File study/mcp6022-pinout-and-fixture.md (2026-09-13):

# MCP6022 Pinout and Its Role in the Fixture

Actuator Health Monitoring System — study note, 2026-09-13.

The breadboard device is the **8-pin PDIP MCP6022**. It contains two operational amplifiers, A and B, which share the same supply connections.

## Find pin 1 on the physical device

Look down at the marked top of the package. Orient the semicircular notch toward the top of the diagram. Pin 1 is at the upper left; a pin-1 dot, when present, is beside that corner. Count counterclockwise: **1–4 down the left side, then 5–8 up the right side**. Use the notch or pin-1 indicator to establish orientation.

MCP6022 PDIP top view: left pins 1, 2, 3, 4; right pins 8, 7, 6, 5; notch at top

This is a top view. Rotating the chip rotates this map; the electrical pin numbers stay fixed.

Pin identities and package orientation are checked against Microchip's package diagram and Table 3-1. [MCP6022 family datasheet, pages 1 and 15](https://ww1.microchip.com/downloads/en/DeviceDoc/20001685E.pdf)

## Every pin, and our connection

| Pin | Datasheet name | Meaning | Connection in our fixture |
| --- | --- | --- | --- |
| 1 | VOUTA | Amplifier A output | `VDRV`: drives R5 and connects to feedback resistor R7 |
| 2 | VINA− | A inverting input | Junction of R6 (`RIN`) and R7 (`RF`) |
| 3 | VINA+ | A non-inverting input | `VREF_BUF`, supplied by pin 7 |
| 4 | VSS | Lower supply rail | PSU GND |
| 5 | VINB+ | B non-inverting input | `VREF_RAW`, junction of divider resistors R3 and R4 |
| 6 | VINB− | B inverting input | Connected directly to pin 7 for buffer feedback |
| 7 | VOUTB | Amplifier B output | `VREF_BUF`: connects to pins 6 and 3 |
| 8 | VDD | Upper supply rail | PSU +5 V |

The last column is derived from the [project schematic](../Schematics/actuator-health/actuator-health.kicad_sch). Pin 7 becomes our reference output because of the external wiring.

## What + and − mean on an amplifier

The input signs describe how a voltage difference influences the output. For amplifier A, increasing pin 3 relative to pin 2 pushes the output upward; increasing pin 2 relative to pin 3 pushes it downward. The same relationship applies to B's pins 5 and 6.

These are analog voltage inputs. The minus sign does not mean “connect this input to ground” or require a negative voltage.

A useful simplified model is:

`Vout = Aopen-loop × (V+ − V−)`

The open-loop gain is large. With suitable negative feedback and operation within the amplifier's limits, a small input difference makes the output settle. This is why we often calculate using **V− ≈ V+**. Feedback creates this approximate equality; the two input pins are not internally shorted.

## Amplifier B: why pins 6 and 7 are joined

R1–R4 form the reference divider. With four equal resistors and a 5 V supply:

`VREF_RAW = 5 V × R4 / (R1 + R2 + R3 + R4) = 1.25 V`

Pin 5 senses this voltage. Pin 6 senses the output because it is connected to pin 7.

If pin 7 is too low, pin 5 is above pin 6 and the amplifier drives pin 7 upward. If pin 7 is too high, feedback drives it downward. It settles near the reference voltage.

The divider supplies very little input current to pin 5. The buffer supplies its connected load from the IC's power rails, keeping loading of the divider small.

Ideally:

`pin 5 ≈ pin 6 = pin 7 ≈ 1.25 V`

Pins 6 and 7 are equal because of their wire connection. The approximate equality to pin 5 depends on correct powered operation and feedback.

## Amplifier A: why pin 2 receives two resistors

Pin 3 sets the reference at `VREF_BUF`. R6 carries the generator input toward pin 2; R7 feeds the output back to that junction.

Using negligible input current and `V(pin 2) ≈ VREF_BUF`, Kirchhoff's current law gives:

`(AFG_IN − VREF_BUF)/R6 + (VDRV − VREF_BUF)/R7 ≈ 0`

Rearranging:

`VDRV ≈ (1 + R7/R6) × VREF_BUF − (R7/R6) × AFG_IN`

For equal R6 and R7:

`VDRV ≈ 2 × VREF_BUF − AFG_IN ≈ 2.5 V − AFG_IN`

An increase at the generator input causes a decrease at pin 1. This approximation applies while the amplifier can supply the required output voltage and current.

Pin 1 drives the series path through R5, Pololu IP+ to IP−, and R8 to ground. Scope CH1 measures the voltage across R8; scope CH2 measures the separate Pololu OUT signal. Scope channel numbers do not identify the MCP6022's internal amplifiers.

## Supply pins and the capacitor

In our single-supply circuit, **pin 8 = +5 V and pin 4 = GND**. VSS denotes the lower supply rail; here it is 0 V. The specified operating supply difference is 2.5–5.5 V. [Microchip datasheet, section 3.5](https://ww1.microchip.com/downloads/en/DeviceDoc/20001685E.pdf)

C1, 100 nF, connects the pin-8 supply node to the pin-4 ground node. Its short local connections let it supply brief current changes and reduce rapid disturbance of the IC's supply. It sits across the rails, while pin 8 also has its direct supply wire. [Microchip supply bypass guidance, section 4.7](https://ww1.microchip.com/downloads/en/DeviceDoc/20001685E.pdf)

The earlier missing pin-8 supply connection and missing divider supply connection were different faults. Powering the IC enables the amplifiers; powering the divider establishes the reference they use.

## Why KiCad shows U1A, U1B, and U1C

These symbols describe **one physical chip**:

| KiCad unit | Physical pins | Role here |
| --- | --- | --- |
| U1A | 1, 2, 3 | Biased inverting driver |
| U1B | 5, 6, 7 | Reference buffer |
| U1C | 8, 4 | Shared power connections |

U1C is the supply symbol, so the drawing still represents two amplifiers and eight physical pins.

The `VREF_RAW` and `VREF_BUF` names belong to our external circuit. The MCP6022 has no dedicated VREF pin; the family datasheet also describes other devices that do. [Microchip datasheet, Table 3-1](https://ww1.microchip.com/downloads/en/DeviceDoc/20001685E.pdf)

## Match the package to the breadboard

With power disconnected when repositioning the IC, place the package across the breadboard's center trench. Its two rows of legs belong on opposite sides of the trench, and successive pins on each side occupy different numbered rows. Breadboard row numbers are not IC pin numbers.

For voltage measurements, name both points explicitly, for example **“MCP6022 pin 7 relative to circuit GND.”** Record the instrument and whether the quantity is DC, RMS, or peak-to-peak.

Continue with [oscilloscope acquisition and triggering](oscilloscope-acquisition-and-triggering.md) to understand how those voltages become waveform records.

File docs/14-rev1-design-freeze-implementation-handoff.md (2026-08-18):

# Phase 14 — Rev-1 Design Freeze and Implementation Handoff

**Status:** Design complete / ready for PR review  
**Project:** Actuator Health Monitoring System

## Purpose

Phase 14 closes Stage A design work by freezing the accepted Rev-1 product baseline and defining the controlled handoff into implementation, calibration and physical verification.

This phase does not redesign accepted subsystems and does not claim that the physical prototype has passed verification. Its purpose is to establish exactly what is frozen, what remains an implementation choice, which measured TBDs must be resolved during Stage B/C, and how changes after freeze are controlled.

## Accepted baseline entering Phase 14

Phases 1–13 are merged and constitute the authoritative Rev-1 design/verification baseline. The integrated product includes:

- Philips/Saeco 24 VDC brew-group gearmotor as Rev-1 actuator;
- Pololu #4048 / ACS724LLCTR-05AU current sensor;
- calibrated 0–5 A unidirectional measurement range;
- MCP6022-based fourth-order approximately 15 kHz Butterworth AFE;
- UNO R4 WiFi / Renesas RA4M1 deterministic 100 kS/s acquisition;
- DC–10 kHz diagnostic band;
- ≤ ±0.10 A mandatory calibrated system-current accuracy target;
- ≤10 mA usable reported-current resolution target;
- current-domain startup/load/ripple/overload/stall/anomaly diagnostics;
- USB PC/MATLAB engineering interface;
- bench-PSU current limiting plus series fuse protection architecture;
- versioned build/calibration/configuration traceability;
- requirement-driven verification and acceptance plan.

## 14.1 — Authoritative Rev-1 design-freeze baseline

### FRZ-001 — Merged Phases 1–13 define the frozen Stage A product baseline

**Status:** Accepted

The merged contents of **Phases 1–13** constitute the authoritative Rev-1 Stage A baseline for requirements, architecture, subsystem design, integration and verification acceptance.

After Phase 14 closes, the following categories are considered frozen product-level decisions unless changed through explicit engineering change control:

- system requirements and accepted performance targets;
- sensor/measurement architecture and calibrated 0–5 A validity range;
- AFE topology and accepted component realization;
- ADC/sampling architecture and deterministic 100 kS/s baseline;
- firmware/signal-processing responsibilities and validity propagation;
- diagnostic architecture and fault/condition model;
- communication architecture and PC/MATLAB boundary;
- power/protection architecture;
- calibration/healthy-reference architecture;
- integrated wiring/build topology and physical partitioning;
- verification methods and mandatory acceptance criteria.

The freeze does **not** mean that every implementation value is already known. Items deliberately deferred to measurement, tuning or implementation remain valid Stage B/C outputs rather than unclosed Stage A design gaps. Examples include motor characterization currents, actual sensor/AFE/ADC behavior, calibration coefficients, diagnostic thresholds/persistence values, healthy-reference values, fuse rating, exact buffer sizes, DSP window/FFT details and measured timing/noise results.

Stage B may choose or tune implementation details only within the boundaries already permitted by the frozen design. Such choices shall not silently change a product requirement, architecture boundary, accepted interface, safety/protection assumption or verification criterion.

If implementation or verification demonstrates that a frozen decision is incorrect, infeasible or materially inadequate, the result shall be retained and the baseline shall be revised explicitly through controlled engineering change. The implementation shall not simply diverge from the documentation without recording that change.

`Stage A design freeze ≠ immutable forever`

but

`material post-freeze change → explicit engineering revision + traceability`

## 14.2 — Frozen versus implementation-selectable items

### FRZ-002 — Implementation freedom is bounded by the frozen product baseline

**Status:** Accepted

Frozen decisions include, at minimum:

- calibrated 0–5 A unidirectional current range;
- ≤ ±0.10 A mandatory calibrated system-current accuracy target;
- ≤10 mA usable reported-current resolution target;
- DC–10 kHz diagnostic information band;
- deterministic 100 kS/s acquisition baseline;
- Pololu #4048 / ACS724LLCTR-05AU + MCP6022 + UNO R4 / RA4M1 measurement architecture;
- fourth-order approximately 15 kHz Butterworth AFE realization and accepted interface boundaries;
- current-domain diagnostic architecture, including overload ≤1 s and current-based stall/jam ≤100 ms acceptance requirements;
- USB PC/MATLAB engineering-interface architecture;
- 24 VDC Rev-1 motor and accepted power/protection philosophy;
- measurement-validity/overrange behavior and independence of protective current limiting from MCU diagnostics;
- mandatory verification and PASS criteria established through Phase 13.

Implementation-selectable or measurement-derived details include, where the earlier baseline deliberately permits them:

- exact RA4M1 ADC/timer/register configuration used to realize deterministic sampling;
- exact DTC/DMA-like transfer strategy;
- acquisition/buffer sizes and internal scheduling details;
- FFT length, window, overlap and related DSP realization details;
- detailed serial framing and integrity mechanism within the accepted communication contract;
- MATLAB script/function/file organization;
- motor-derived diagnostic thresholds, persistence/tuning values and healthy-reference values;
- measured calibration coefficients and calibration identity;
- final fuse rating selected from motor characterization and current-path capability;
- exact physical component placement/routing that preserves the frozen wiring/isolation rules.

An implementation-selectable choice becomes a controlled design change if it alters or invalidates a frozen requirement, architecture boundary, safety assumption, interface contract or acceptance criterion.

Examples: changing FFT length while preserving accepted behavior is an implementation choice; changing 100 kS/s to 20 kS/s is not. Tuning a stall threshold from measured motor data is an implementation choice; replacing the ACS724 architecture is not.

`implementation freedom is permitted only inside the frozen Rev-1 design envelope`

## 14.3 — Measured-TBD register and closure ownership

### FRZ-003 — Deferred measured values remain explicit until Stage B/C evidence closes them

**Status:** Accepted

Values intentionally left unknown during Stage A remain in a controlled measured-TBD register. A TBD shall not be removed merely by assuming or estimating a convenient value where physical characterization or verification is required.

| Measured / derived TBD | Primary closure stage | Closure evidence / purpose |
| --- | --- | --- |
| motor no-load current | Stage B characterization | measured repeatable operating-current data |
| motor representative loaded current | Stage B characterization | controlled load/current observations |
| startup/inrush peak and duration | Stage B characterization | captured startup waveform and conditions |
| current under controlled stall/jam | Stage B characterization | current-limited safe stall waveform/data |
| actual ACS724 zero-current output | Stage B calibration | measured sensor/chain zero behavior |
| actual ACS724/chain sensitivity and gain | Stage B calibration | reference-current calibration data |
| complete-chain offset/gain calibration coefficients | Stage B calibration | fitted calibration record with calibration ID |
| implemented AFE frequency response | Stage B, confirmed Stage C | measured transfer-response evidence |
| ADC/complete-chain noise and effective resolution | Stage B, confirmed Stage C | raw data and noise/resolution statistics |
| actual 100 kS/s timing and jitter behavior | Stage B, confirmed Stage C | independent timing evidence |
| normal motor ripple/commutation/spectral characteristics | Stage B characterization | valid waveform/spectral captures |
| healthy-reference feature values/tolerances | Stage B characterization/calibration | healthy baseline and reference configuration |
| overload threshold/persistence values | Stage B diagnostic tuning | motor-derived configuration verified against ≤1 s |
| stall/jam threshold/persistence values | Stage B diagnostic tuning | motor-derived configuration verified against ≤100 ms |
| anomaly thresholds/tolerances | Stage B diagnostic tuning | healthy/fault evidence supporting configuration |
| final inline fuse rating | Stage B after motor characterization | selection from measured current and path capability |
| bench-PSU current-limit settings | Stage B/C procedure setup | documented safe settings appropriate to test |
| complete-chain calibrated accuracy across 0–5 A | Stage C verification | independent evidence against ±0.10 A |
| usable ≤10 mA reported-current resolution | Stage C verification | controlled distinguishability/noise evidence |
| final diagnostic latency and false-detection performance | Stage C verification | timestamped event evidence |

Stage B owns characterization, calibration, implementation and tuning. Stage C owns independent acceptance evidence where a measured value is tied to a mandatory requirement. A Stage B measurement does not automatically count as Stage C acceptance where Phase 13 requires independent verification.

Every closed TBD retains enough context to identify the build, firmware, calibration/configuration, motor and test condition. A later implementation change that invalidates the measurement reopens the affected item. No numerical value is introduced solely to eliminate a TBD.

## 14.4 — Stage B implementation sequence and entry criteria

### FRZ-004 — Progressive subsystem bring-up before complete Rev-1 integration

**Status:** Accepted

Stage B proceeds progressively:

`inspect/setup → motor characterization → ACS724 bring-up → AFE bring-up → deterministic ADC acquisition → calibration/current conversion → USB/MATLAB → healthy characterization → diagnostics tuning → protection finalization → complete build → integration checks`

Working sequence:

1. inspect parts and establish safe bench/current-limit setup;
2. characterize the 24 V motor;
3. bring up and characterize the ACS724 carrier;
4. build and characterize the MCP6022 AFE independently;
5. implement and characterize deterministic RA4M1 100 kS/s acquisition;
6. integrate calibration, current conversion and validity behavior;
7. implement USB transport and MATLAB engineering tooling;
8. characterize healthy motor-current signatures;
9. tune overload/stall/anomaly configuration from measured behavior;
10. finalize fuse and current-limit configuration;
11. assemble the complete Rev-1 build;
12. perform Stage B integration checks before formal acceptance.

Stage B may begin after Phase 14 is approved/merged, the items needed for the next activity are available, the applicable frozen design can be identified, and the work can be performed without violating an unresolved safety dependency. Material defects are resolved, documented as limitations, or escalated through engineering change before dependent acceptance work proceeds.

## 14.5 — Stage C verification sequence and evidence handoff

### FRZ-005 — Formal acceptance uses a stable identified Stage B configuration

**Status:** Accepted

Stage B develops, characterizes, calibrates and tunes the system. Stage C independently determines whether the resulting Rev-1 configuration satisfies the frozen requirements and Phase 13 acceptance criteria.

The Stage C sequence follows the Phase 13 hierarchy:

`component/subsystem → measurement chain → diagnostics/data → complete system`

Before formal Stage C acceptance, Stage B shall hand over a stable identified configuration including, as applicable:

`Build ID + hardware revision + firmware revision + calibration ID + configuration ID + motor ID`

Formal acceptance evidence shall be produced against that identified configuration. Acceptance tests shall not be silently converted into tuning sessions. If a mandatory test fails, the observed FAIL is retained. The system returns to Stage B for correction/tuning where appropriate; the changed calibration/configuration/build receives a distinguishable identity; and affected verification is repeated.

For example, if current-based stall detection is measured at 140 ms against the mandatory ≤100 ms criterion, the test is FAIL for that configuration. Adjusting a threshold or persistence parameter creates a changed configuration and requires the affected verification to be rerun rather than rewriting the original result.

Stage C evidence shall retain the traceability and result-status requirements established in Phase 13. Only evidence belonging to the accepted configuration may support final Rev-1 acceptance unless an explicit analysis demonstrates that a particular unchanged result remains valid across a controlled revision.

## 14.6 — Engineering change control after design freeze

### FRZ-006 — Material post-freeze changes require explicit impact analysis and re-verification

**Status:** Accepted

A post-freeze change is material when it affects a frozen requirement, product/component architecture, electrical interface, safety/protection assumption, sampling or diagnostic architecture, calibration meaning, communication contract or verification PASS criterion.

Material changes follow:

`problem/evidence → impact analysis → proposed change → approval → baseline update → implementation → affected verification repeated`

The change record shall identify why the frozen baseline is inadequate, what is changed, which requirements/design documents/configurations are affected, and which prior characterization or verification evidence must be repeated or invalidated.

Implementation-selectable details already permitted by FRZ-002 do not require formal change control merely because a low-level implementation choice is made. They do require normal configuration/source-control traceability where relevant.

A failed test shall not be hidden by silently modifying the requirement or implementation. The original result remains part of the engineering record; correction and re-verification establish the new result.

## 14.7 — Future FPGA / Verilog extension boundary

### FRZ-007 — FPGA/Verilog processing is a post-Rev-1 extension, not a Rev-1 dependency

**Status:** Accepted

The frozen Rev-1 signal path remains:

`ACS724 → analog AFE → RA4M1 → USB → PC/MATLAB`

FPGA/Verilog work is explicitly reserved as a future engineering extension after Rev-1 implementation and verification. It is not required to build, calibrate or accept Rev-1 and shall not become an implementation blocker.

A future extension may reuse live or recorded Rev-1 current data to investigate hardware realization of functions such as digital filtering, mean/RMS/peak calculations, threshold/event detection, spectral processing, fixed-point arithmetic, pipelining and deterministic streaming processing.

The engineering purpose is to compare suitable MCU software DSP with FPGA hardware processing and study the consequences for determinism, throughput, latency, numeric representation and resource use. FPGA functionality shall not be added merely to claim that the project contains Verilog.

If a future FPGA revision changes the accepted acquisition/diagnostic architecture, it becomes a separately controlled revision rather than being retroactively treated as part of Rev-1.

## 14.8 — Final Stage A completeness audit and implementation handoff

### FRZ-008 — Stage A closes only after a cross-phase implementation-readiness audit

**Status:** Accepted

The final Stage A audit reviewed the authoritative Phase 1–13 baseline together with the Phase 14 freeze decisions for:

1. **consistency** — later decisions do not silently contradict frozen requirements;
2. **completeness** — the product architecture and interfaces needed to begin implementation are defined;
3. **TBD correctness** — remaining unknowns genuinely require implementation, characterization, tuning or verification rather than representing forgotten Stage A decisions;
4. **verification closure** — mandatory Rev-1 requirements have measurable verification routes and objective acceptance logic.

The audit specifically cross-checked the Phase 1 requirements against the later sensor/AFE/ADC, firmware/diagnostic, communication, power/protection, calibration, integration and Phase 13 verification baselines. The major frozen values remain coherent: 0–5 A calibrated unidirectional range, DC–10 kHz diagnostic band, 100 kS/s deterministic acquisition, ≤±0.10 A mandatory calibrated accuracy, ≤10 mA reported-current resolution, overload ≤1 s, current-based stall/jam ≤100 ms and ≤24 VDC Rev-1 laboratory operation.

The audit also confirmed that higher-frequency characterization above 10 kHz remains a validation obligation rather than being lost at freeze; deterministic acquisition remains hardware-timed and independent of USB workload; communication remains versioned/integrity-aware downstream of acquisition; protection remains independent of diagnostic shutdown; and Stage C acceptance remains requirement-driven rather than inferred from Stage B bring-up success.

No implementation-blocking Stage A contradiction or missing product-level decision was identified. Remaining open numerical values are appropriately measurement/configuration-derived and are controlled by FRZ-003. Register-level firmware details, buffer/DSP choices, calibration coefficients, motor-derived thresholds, healthy-reference values, fuse rating and measured performance are therefore legitimate Stage B/C outputs rather than reasons to continue Stage A design.

### Handoff decision

**READY FOR STAGE B IMPLEMENTATION**, subject to Phase 14 PR review and merge.

This decision means the design is sufficiently defined to begin implementation. It does **not** mean that the physical Rev-1 has passed any Stage C acceptance test.

If Stage B exposes a frozen assumption that is physically incorrect or infeasible, FRZ-006 engineering change control applies.

## Phase 14 closure summary

Accepted Phase 14 decisions:

1. **FRZ-001** — authoritative Rev-1 Stage A baseline;
2. **FRZ-002** — frozen versus implementation-selectable boundary;
3. **FRZ-003** — measured-TBD register and closure ownership;
4. **FRZ-004** — Stage B implementation sequence and entry criteria;
5. **FRZ-005** — Stage C verification sequence and evidence handoff;
6. **FRZ-006** — engineering-change control after freeze;
7. **FRZ-007** — future FPGA/Verilog extension boundary;
8. **FRZ-008** — final Stage A audit and READY FOR STAGE B handoff decision.

The proposed procurement-blocker work package was rejected during review and is not part of the Phase 14 baseline.

## Completion criterion

Phase 14 is complete when this document is approved and merged. At that point Stage A design is frozen and complete, and work proceeds to Stage B implementation under the controlled baseline above.

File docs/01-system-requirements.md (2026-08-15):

# Phase 1 — System Requirements

**Status:** Complete / baselined  
**Project:** Actuator Health Monitoring System

## Purpose

Phase 1 defines what the Rev-1 laboratory system must measure and what operating behaviours it must support before implementation details are selected.

The Rev-1 system is a low-voltage DC actuator/motor condition-monitoring prototype based on current measurement and waveform analysis. The architecture should remain conceptually scalable toward future industrial three-phase motor monitoring, but Rev-1 hardware is not industrial-rated equipment.

## REQ-SIG-001 — Current measurement and waveform analysis

**Status:** Accepted

The system shall acquire sufficient current-waveform information to characterize:

- average actuator load,
- startup behaviour,
- commutation/current ripple,
- changing mechanical load,
- overload,
- and stall conditions.

The acquired data shall support both time-domain and frequency-domain analysis.

## REQ-BW-001 — Diagnostic measurement bandwidth

**Status:** Accepted

The current-acquisition subsystem shall preserve diagnostic signal content from DC through 10 kHz.

`DC–10 kHz` means signal content from 0 Hz through 10,000 Hz. It includes average current, slow variations, periodic components, harmonics, commutation ripple, and other diagnostic content within this band.

## REQ-BW-002 — Higher-frequency characterization

**Status:** Accepted

Frequency components above the diagnostic bandwidth shall be characterized with laboratory instrumentation during validation to determine whether extending the acquisition bandwidth is justified.

## Phase 1 baseline decisions

### 1. Rev-1 actuator class

- Rev-1 uses a low-voltage DC actuator/motor.
- A brushed DC motor is preferred for laboratory validation because it is simple to drive and produces useful commutation-current structure.
- The architecture shall remain replaceable at the sensing front end for future industrial three-phase monitoring.

### 2. Electrical operating envelope

- Current-measurement range: **0–5 A**, constrained by the selected ACS724-05AU sensor.
- Monitoring electronics: nominally **5 V where applicable**.
- Rev-1 actuator supply: low-voltage DC, **maximum architectural limit 24 V**.
- Exact motor operating voltage/current remains dependent on final motor selection.

### 3. Operating behaviours and faults

The system shall support characterization of:

- startup/inrush,
- normal running,
- changing mechanical load,
- commutation/current-spectrum behaviour,
- overload,
- stall.

### 4. Sampling frequency

Nominal acquisition target: **100 kS/s**.

At 100 kS/s:

- sampling period = **10 µs**,
- Nyquist frequency = **50 kHz**,
- a 10 kHz signal is represented by 10 samples per period,
- the 10–50 kHz region provides practical transition space for analog anti-alias filtering.

The theoretical Nyquist minimum for 10 kHz bandwidth is not treated as an adequate practical design target.

### 5. Measurement accuracy

Laboratory system-level target after calibration: **≤ ±0.10 A**.

Stretch target: **±0.05 A**.

Reported current resolution target: **≤ 10 mA**.

ADC bit resolution alone shall not be treated as measurement accuracy. The final error budget must include sensor, analog-front-end, ADC, reference/supply, noise, temperature, and calibration effects.

### 6. Overload definition

Overload shall be based on:

- current above a configurable overload threshold,
- persisting longer than a configurable persistence time.

Threshold and persistence values shall be derived from characterization of the actual test actuator rather than guessed in Phase 1.

### 7. Stall definition

Physical stall means a powered/commanded actuator is not rotating.

Because Rev-1 is initially current-only, stall detection shall be inferred from current behaviour. Candidate indicators include:

- elevated current,
- loss/reduction/change of normal commutation behaviour,
- persistence for a defined interval.

Exact stall criteria remain to be experimentally derived.

### 8. Fault-detection latency

Targets:

- stall: **≤ 100 ms** after stall criteria become valid,
- sustained overload: **≤ 1 s** after overload criteria become valid.

Persistence parameters remain configurable and require later validation.

### 9. Protection philosophy

- During early development, the bench power supply current limit is the primary actuator-side protection.
- Measurement and diagnosis are validated before automatic shutdown is enabled.
- A later design may use a MOSFET, relay, or external protection interface commanded by diagnostics.
- Critical faults may later be latched until reset.

### 10. Laboratory environment

Rev-1 baseline:

- indoor laboratory,
- approximately 20–30 °C,
- dry environment,
- low-voltage DC actuator supply ≤24 V,
- nominal monitoring electronics around 5 V where applicable,
- short laboratory wiring.

Later characterization should intentionally investigate supply variation, noise, motor-generated disturbances, and temperature influence where justified.

### 11. Verification approach

Requirements shall be verified using combinations of:

- engineering analysis and calculations,
- inspection,
- controlled laboratory testing,
- demonstration.

Objective evidence may include:

- oscilloscope measurements,
- multimeter/reference readings,
- bench-supply settings/readings,
- raw ADC logs,
- firmware logs,
- MATLAB analysis and plots.

## Key fixed Rev-1 hardware constraints established before detailed design

- Current sensor: Pololu #4048 using Allegro ACS724LLCTR-05AU, 0–5 A unidirectional.
- MCU platform: Arduino UNO R4 WiFi / Renesas RA4M1.
- Oscilloscope: HANMATEK DOS1102S with waveform generator.
- Bench supply: Jesverty SPS-3010V.
- AFE experimentation op-amp: MCP6022-I/P.

These selections constrain later design work but do not by themselves prove that the system meets the Phase 1 performance requirements.

## Safety scope

Rev-1 is a low-voltage laboratory system. The Pololu ACS724 carrier, Arduino, breadboard, and ordinary oscilloscope probes shall not be connected directly to an industrial 400 V three-phase circuit. Future industrial implementation requires appropriately rated isolated transducers and installation practices.

## Phase 1 baseline summary

Phase 1 establishes the Rev-1 measurement purpose, operating range, diagnostic bandwidth, nominal sampling rate, accuracy target, target operating/fault conditions, detection-latency goals, protection philosophy, laboratory environment, and verification method.

**Phase 1 status: COMPLETE / BASELINED**

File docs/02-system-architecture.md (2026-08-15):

# Phase 2 — System Architecture

**Status:** Complete / baselined  
**Project:** Actuator Health Monitoring System

## ARCH-001 — System boundary

**Status:** Accepted

The Actuator Health Monitoring System shall include the current-sensing front end, analog signal conditioning, ADC acquisition, embedded processing, diagnostics, and communication functions.

The actuator, its mechanical load, power source, PC/MATLAB environment, and laboratory instruments shall remain external to the core monitoring system.

The monitoring system may provide a shutdown command, while the high-power switching equipment may remain outside the core monitoring system.

### Rationale

This separation keeps the monitoring architecture modular. The laboratory current-sensing front end can later be replaced by appropriately rated industrial current transducers without requiring the complete acquisition, processing, diagnostic, and communication architecture to be redesigned.

## ARCH-002 — Subsystem decomposition

**Status:** Accepted

The Actuator Health Monitoring System shall consist of six logical subsystems:

1. **Current sensing** — converts actuator current into an analog measurement signal.
2. **Analog front end (AFE)** — protects, buffers, conditions, and anti-alias filters the sensor signal before ADC conversion.
3. **ADC acquisition** — samples the conditioned analog signal at deterministic times and buffers the resulting digital samples.
4. **Signal processing** — converts samples into calibrated electrical quantities and extracts time-domain and frequency-domain features.
5. **Diagnostics** — interprets measurements and extracted features to determine operating state and faults such as overload or stall.
6. **Communication** — transfers measurements, diagnostics, status, and engineering data through UART, CAN, and RS-485 interfaces.

Protection/shutdown control shall be treated as a future extension driven by the diagnostics subsystem.

### Rationale

Separating measurement, processing, diagnostics, and communication keeps responsibilities clear and allows individual subsystems to evolve independently. In particular, future industrial current-sensing hardware can replace the laboratory ACS724 sensing front end while retaining much of the downstream acquisition, processing, diagnostics, and communication architecture.

The anti-alias filter is part of the Analog Front End rather than a separate subsystem because it prepares the analog signal specifically for ADC conversion.

## ARCH-003 — Explicit subsystem interfaces

**Status:** Accepted

The six logical subsystems shall communicate through explicitly defined interfaces. Physical sensing and analog interfaces shall be separated from digital processing and diagnostic interfaces so that sensing hardware can be replaced without unnecessary changes to downstream software.

### Interface classes

| Interface | Source → Destination | Information type |
|---|---|---|
| IF-01 | Actuator current → Current sensing | Physical electrical current |
| IF-02 | Current sensing → Analog front end | Analog sensor voltage |
| IF-03 | Analog front end → ADC acquisition | Conditioned analog voltage |
| IF-04 | ADC acquisition → Signal processing | Timestamped digital samples |
| IF-05 | Signal processing → Diagnostics | Calibrated current values and extracted features |
| IF-06 | Diagnostics → Communication | Operating state, warning and fault information |
| IF-07 | Communication → External device | UART / CAN / RS-485 data |
| IF-08 (future) | Diagnostics → Protection system | Shutdown / control command |

### Rationale

Explicit interface definitions support modularity and make the architecture scalable. A future industrial current transducer may replace the ACS724 sensing subsystem provided the downstream analog interface remains compatible or is adapted by the AFE.

## ARCH-004 — Data representation and traceability

**Status:** Accepted

The acquisition and processing architecture shall preserve four distinct data levels:

1. **Raw ADC samples** — direct ADC conversion results before calibration.
2. **Calibrated current measurements** — samples converted into physical current units.
3. **Calculated features** — time-domain and frequency-domain properties derived from windows or blocks of samples.
4. **Diagnostic information** — operating states, warnings, and fault flags derived from measurements and features.

Raw ADC data shall remain accessible for calibration, validation, and debugging.

Deterministic sample timing shall be represented by a known sampling period and sample index. Acquisition blocks may carry an absolute or block-start timestamp rather than storing a separate timestamp with every individual sample.

### Example data flow

```text
raw ADC samples
       |
       v
calibrated current [A]
       |
       v
features
(mean / RMS / peak / ripple / spectrum)
       |
       v
diagnostic state
(NORMAL / WARNING / FAULT)
```

### Rationale

Separating raw measurements, engineering quantities, calculated features, and diagnostic interpretation preserves traceability. It allows MATLAB analysis and validation to return to the original ADC samples rather than relying only on processed or classified outputs.

At a nominal sampling rate of 100 kS/s, the sampling interval is 10 us. A known block-start time plus sample index is sufficient to reconstruct individual sample times while avoiding unnecessary timestamp storage for every sample.

## ARCH-005 — Power-domain architecture

**Status:** Accepted

The Rev-1 system shall separate the actuator power domain from the monitoring-electronics power domain.

The actuator shall be powered from an external low-voltage DC source.

The current-sensor signal electronics, Analog Front End, and MCU shall operate from the low-voltage monitoring domain, nominally 5 V where applicable, and shall share a defined signal-ground reference.

Local supply decoupling shall be provided at the sensing and analog circuitry.

The actuator-current conductor and low-voltage sensor electronics shall remain galvanically separated through the current-sensing element.

A later development stage shall investigate operation from a common external supply with protection, regulation, filtering, and measured supply-noise performance.

### Rationale

Separating the actuator and monitoring supplies establishes a controlled low-noise baseline for sensor and ADC validation. Motor switching, startup current, commutation, and load transients can disturb the actuator supply; keeping the sensitive measurement electronics on a separate supply initially prevents those disturbances from being unintentionally coupled into every measurement.

The monitoring-side ACS724 output, AFE, and ADC require a common signal reference so that the sensor output voltage is interpreted correctly. The high-current conductor itself remains galvanically separated from this signal-ground domain through the Hall-effect sensing element.

## ARCH-006 — Industrial scalability

**Status:** Accepted

The architecture shall not assume that the system permanently contains only one current-measurement channel.

Rev-1 shall implement one current channel for a low-voltage DC actuator.

A future industrial implementation shall permit multiple isolated current-sensing channels, including three phase-current channels for a three-phase motor.

Multi-channel acquisition shall preserve known inter-channel timing; simultaneous or appropriately synchronized acquisition shall be used when phase relationships are required.

Sensor-specific scaling and calibration shall be isolated from downstream signal-processing and diagnostic functions so that alternative current transducers can be introduced without unnecessary redesign of those functions.

Industrial voltage measurement may be added as a future extension but is not part of the Rev-1 baseline.

### Rationale

A single-channel laboratory prototype is sufficient for the first DC-actuator implementation, while industrial three-phase condition monitoring may require separate current information from L1, L2, and L3. Keeping channel handling and sensor calibration modular allows the acquisition architecture to scale without tying downstream algorithms to the ACS724 or to a permanently single-channel design.

Known inter-channel timing is necessary when comparing phase relationships. Simultaneous sampling is preferred when exact phase comparison is required; precisely synchronized or characterized sequential acquisition may be used where its timing error is acceptable.

## ARCH-007 — Architecture verification and traceability

**Status:** Accepted

Every accepted system requirement shall be mapped to at least one responsible subsystem or interface.

Architecture verification shall confirm that the complete measurement path from sensing through acquisition, processing, diagnostics, and communication supports the Phase 1 requirements.

During implementation, subsystem and end-to-end tests shall use controlled stimuli and measurable pass criteria.

Verification evidence shall be retained where practical, including raw data, oscilloscope measurements, multimeter/reference measurements, firmware logs, and MATLAB results.

Requirement traceability shall follow:

```text
Requirement
    |
    v
Architecture
    |
    v
Design
    |
    v
Implementation
    |
    v
Verification
    |
    v
Measured result / evidence
    |
    v
PASS / FAIL
```

### Phase 1 requirement-to-architecture coverage

| Phase 1 need | Responsible architecture |
|---|---|
| Measure 0–5 A | Current sensing |
| Preserve diagnostic content from DC through 10 kHz | Current sensing + AFE + ADC acquisition |
| Nominal 100 kS/s acquisition | ADC acquisition |
| Calibrated current-accuracy target | Current sensing + AFE + ADC + calibration |
| Detect startup/inrush | Signal processing + diagnostics |
| Detect overload | Signal processing + diagnostics |
| Detect stall | Signal processing + diagnostics |
| Preserve raw samples | ADC acquisition + data architecture |
| Support MATLAB analysis | Communication + raw-data traceability |
| UART / CAN / RS-485 | Communication |
| Future shutdown | Diagnostics + IF-08 protection interface |
| Future three-phase scalability | Replaceable sensing + multi-channel architecture |

### Rationale

Architecture verification at this stage does not claim that the final hardware already satisfies the performance requirements. It verifies that each accepted requirement has a defined implementation path through the architecture. Physical compliance will later be demonstrated through calculations, controlled laboratory tests, reference measurements, logged data, and end-to-end fault-injection tests.

## System context

```text
External actuator supply
        |
        v
Actuator / motor ---- Mechanical load
        |
        | measured current
        v
==================================================
       ACTUATOR HEALTH MONITORING SYSTEM
==================================================
Current sensing
        |
Analog front end
(protection / buffering / anti-alias filtering)
        |
ADC acquisition
        |
Signal processing
        |
Diagnostics
        |
Communication
(UART / RS-485 / CAN)
==================================================
        |
        v
External PC / MATLAB / industrial controller

Separate monitoring-electronics supply:
5 V monitoring rail -> sensor electronics / AFE / MCU
```

Laboratory oscilloscope, multimeter, and bench power supply are external development and verification tools.

## Phase 2 baseline summary

Phase 2 establishes a modular architecture with clear system boundaries, six logical subsystems, explicit interfaces, traceable data levels, separated actuator and monitoring power domains, a path to future multi-channel industrial sensing, and a verification framework connecting requirements to objective evidence.

No implementation-level component values, filter topology, PCB layout, firmware architecture, or diagnostic thresholds are frozen by Phase 2 unless already established as Phase 1 constraints. Those topics are intentionally deferred to later design and validation phases.

**Phase 2 status: COMPLETE / BASELINED**

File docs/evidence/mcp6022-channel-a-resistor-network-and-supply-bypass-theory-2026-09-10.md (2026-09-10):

# MCP6022 channel-A resistor network and supply-bypass theory — 2026-09-10

**Project:** Actuator Health Monitoring System  
**Stage:** Stage B — ACS724 dynamic/FILTER validation fixture  
**Status:** Theory/study record based on the measured MCP6022 bring-up; no new ACS724 FILTER decision

## 1. Purpose

This record explains two concepts that are required before the temporary MCP6022 positive-bias fixture is loaded by the ACS724 primary-current path:

1. the complete resistor/feedback architecture around MCP6022 channel A and why it implements a level shifter;
2. the purpose of the local and bulk supply-bypass capacitors and why the bulk capacitor is added before loaded dynamic operation.

The explanations below deliberately separate **what sets a voltage**, **what carries current**, and **what negative feedback forces the op-amp to do**.

This file is educational implementation evidence. It does not alter the frozen Rev-1 AFE design.

---

## 2. Measured context already established

The temporary fixture has already produced the following measured results:

- MCP6022 supply between pins 8 and 4: approximately **4.99 V**;
- buffered reference on channel B: approximately **1.242–1.245 V**;
- channel-A resistors:
  - `RIN = 99.1 kOhm`;
  - `RF = 99.0 kOhm`;
- channel-A pin-1 DC output with zero external input: approximately **2.49 V**;
- unloaded 100 Hz dynamic test:
  - AFG/input CH1: approximately **520 mVpp**;
  - MCP6022 pin-1 output CH2: approximately **504 mVpp**;
  - output DC centre: approximately **2.480 V**;
  - output visibly inverted relative to input.

These observations are consistent with the intended level-shifter relation derived below.

---

# Part I — Channel-A resistor and feedback architecture

## 3. Exact channel-A connection list

Relevant MCP6022 channel-A pins:

- pin 1 = `OUTA`;
- pin 2 = `-INA`;
- pin 3 = `+INA`.

Connections used for the temporary level shifter:

1. `pin 3 (+INA) -> VREF_BUF`, the buffered approximately 1.245 V reference produced by channel B.
2. `RIN = 99.1 kOhm` connects between the AFG output node and pin 2.
3. `RF = 99.0 kOhm` connects between pin 1 and pin 2.
4. Pin 2 is therefore the junction of `RIN` and `RF`.
5. Pin 1 is the driven output node; it is **not** the resistor junction.
6. The AFG ground is common with MCP6022 VSS/GND.
7. During the earlier DC-only validation, the AFG side of `RIN` was temporarily connected to GND so that `VIN = 0 V` was known exactly.

The resistor network is therefore an **inverting amplifier referenced to a non-zero voltage** rather than to ground.

---

## 4. The three voltages that must not be confused

Define:

- `VIN` = voltage on the AFG side of `RIN`;
- `VREF` = voltage on pin 3, approximately 1.245 V;
- `VOUT` = voltage on pin 1.

Pin 2 is the inverting-input node. Call it `VX`.

Because the op-amp is operated with negative feedback, the closed-loop circuit drives its output so that, to a very good approximation:

`VX ~= VREF`

This does **not** mean pin 2 and pin 3 are physically connected. They are separate pins. The equality is an operating result created by the feedback loop.

The phrase often used in op-amp analysis is **virtual short** or **virtual equality**:

- the voltages are almost equal;
- there is no actual short circuit between them;
- essentially no signal current needs to flow from pin 3 to pin 2.

For this fixture:

`pin 3 ~= 1.245 V`

therefore negative feedback keeps:

`pin 2 ~= 1.245 V`.

---

## 5. Why pin 2 stays near the reference voltage

The MCP6022 has very large open-loop gain. Conceptually:

`VOUT = AOL * (V+ - V-)`

For channel A:

- `V+ = pin 3 = VREF`;
- `V- = pin 2 = VX`.

If `VX` falls slightly below `VREF`, then `V+ > V-` and the output stage drives pin 1 upward.

Because pin 1 is connected back to pin 2 through `RF`, raising pin 1 sends corrective current through `RF` and raises the pin-2 node.

If `VX` rises slightly above `VREF`, the opposite happens: the output moves downward and the feedback current changes direction until pin 2 returns close to the reference.

Thus the feedback loop continuously acts to make:

`pin 2 ~= pin 3`.

This is the fundamental condition that allows the resistor equations below to determine the output voltage.

---

## 6. Why current through RIN must also flow through RF

At pin 2 there are three possible current paths:

1. through `RIN` toward the input source;
2. through `RF` toward the output;
3. into the MCP6022 inverting input itself.

The MCP6022 uses CMOS inputs and its input bias current is extremely small compared with the microampere-scale resistor currents in this fixture. For first-order circuit analysis, the current into pin 2 is therefore approximated as zero:

`Ipin2 ~= 0`.

Kirchhoff's Current Law at pin 2 then requires the resistor currents to balance.

Using currents leaving pin 2 as positive:

`(VX - VIN)/RIN + (VX - VOUT)/RF ~= 0`

and because negative feedback gives:

`VX ~= VREF`,

the equation becomes:

`(VREF - VIN)/RIN + (VREF - VOUT)/RF = 0`.

This single node equation explains the whole level shifter.

---

## 7. Derivation of the general level-shifter equation

Starting from:

`(VREF - VIN)/RIN + (VREF - VOUT)/RF = 0`

move the second term to the other side:

`(VREF - VOUT)/RF = -(VREF - VIN)/RIN`

multiply by `RF`:

`VREF - VOUT = -(RF/RIN)*(VREF - VIN)`

expand the right-hand side:

`VREF - VOUT = -(RF/RIN)*VREF + (RF/RIN)*VIN`

solve for `VOUT`:

`VOUT = VREF + (RF/RIN)*VREF - (RF/RIN)*VIN`

therefore:

`VOUT = (1 + RF/RIN)*VREF - (RF/RIN)*VIN`.

This is the general equation for the present resistor arrangement.

---
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

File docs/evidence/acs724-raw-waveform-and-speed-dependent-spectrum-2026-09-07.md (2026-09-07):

# ACS724 Raw Waveform Export and Speed-Dependent Spectrum — 2026-09-07

**Status:** Stage B/C bench evidence record  
**Sensor:** Pololu #4048 / ACS724LLCTR-05AU  
**Oscilloscope:** HANMATEK DOS1102S  
**Date:** 2026-09-07

## 1. Purpose

This record continues `acs724-motor-validation-and-noise-2026-09-07.md`. The earlier scope FFT work was exploratory and screenshot-based. This experiment establishes a numerical DOS1102S CSV export path and uses exported CH1 samples for reproducible OFF/ON and motor-speed spectral comparisons.

The calibrated low-current sensor sensitivity remains:
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

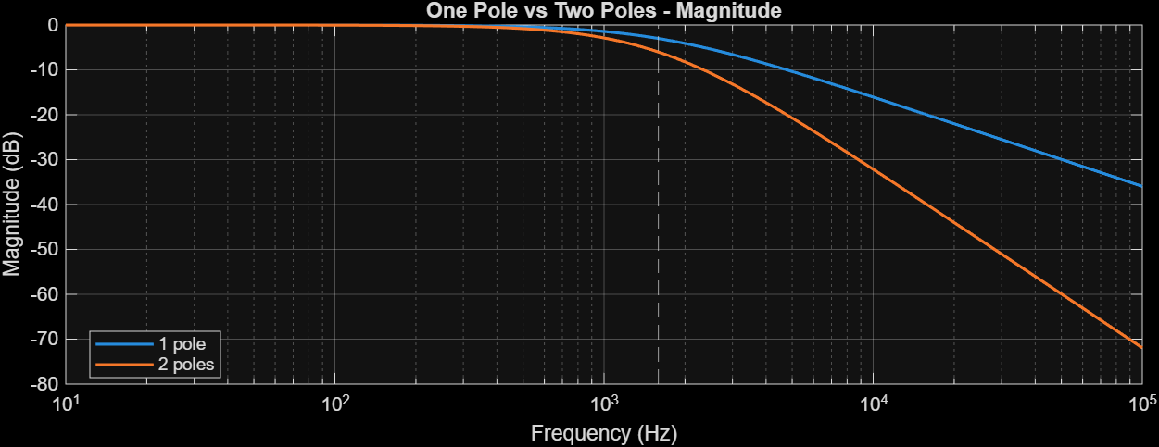
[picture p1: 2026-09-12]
Matlab/twopolemag.png

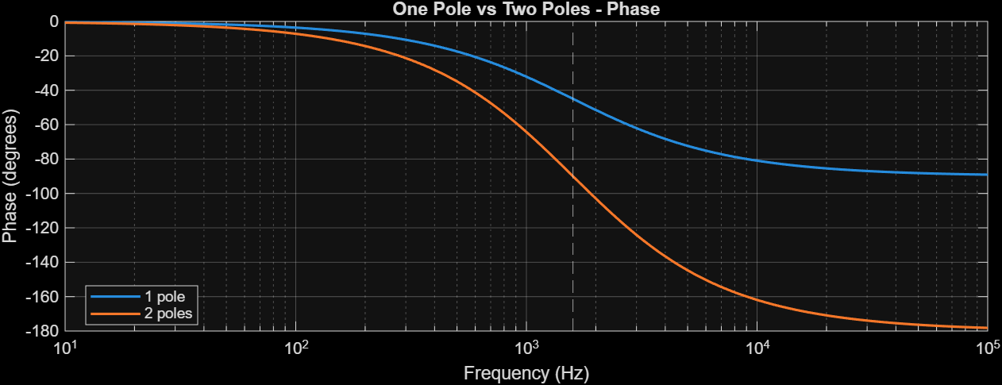
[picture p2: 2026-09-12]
Matlab/twopolephase.png

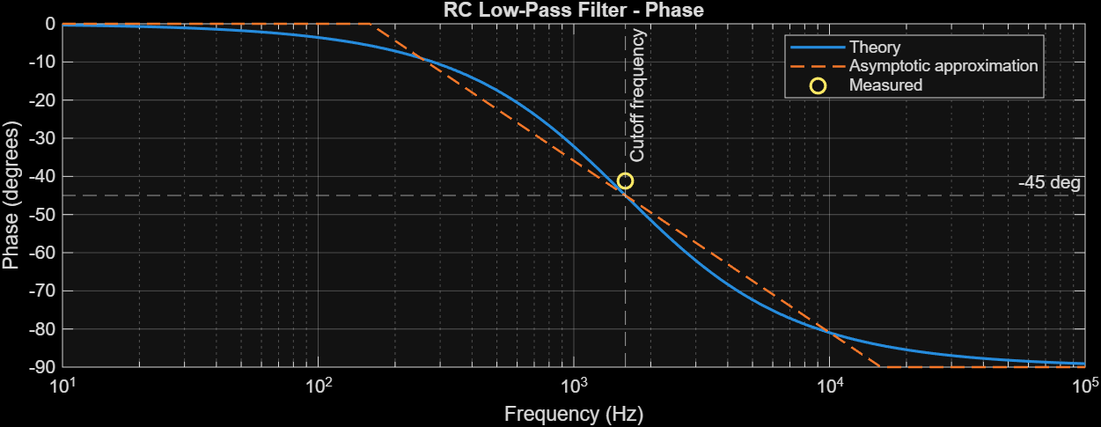
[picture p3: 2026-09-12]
Matlab/RCPhase.png

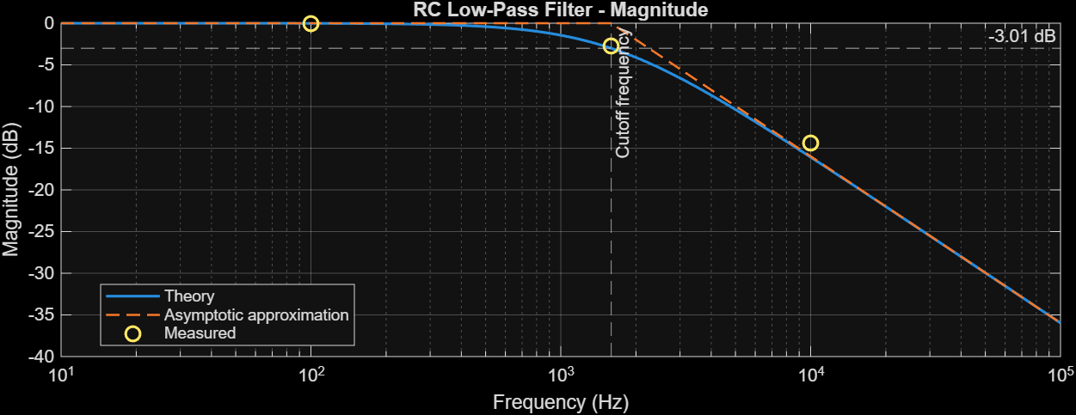
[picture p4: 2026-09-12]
Matlab/RCMag.png

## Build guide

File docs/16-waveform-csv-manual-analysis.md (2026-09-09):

# Waveform CSV Manual Analysis Workflow

**Project:** Actuator Health Monitoring System  
**Purpose:** Define a repeatable manual method for interpreting DOS1102S CSV waveform exports during ACS724 dynamic/filter verification.

## 1. Current channel convention

For the present dynamic-response bench setup, the physical channel assignment is fixed as:

- **CH1 = voltage across the 68 Ω reference resistor**
- **CH2 = ACS724 VOUT**

This mapping is a laboratory wiring convention. A CSV file itself identifies only the oscilloscope channel; it does not know what physical node the probe was connected to. Therefore every analysis shall first confirm both the CSV header channel and the documented physical wiring.

## 2. One CSV per channel

The DOS1102/DOS1102S CSV save workflow uses a selected waveform source such as CH1 or CH2. In the files generated during this project, each CSV contains one channel column and identifies that channel in the header.

Therefore, when both input/reference current and ACS724 output are required for quantitative comparison, save **two CSV files for the same operating condition**:

1. CH1 CSV — reference-resistor waveform;
2. CH2 CSV — ACS724 output waveform.

Both files shall be captured without changing generator frequency/amplitude, filter configuration, wiring, timebase, probe attenuation, coupling, or acquisition settings between them where practical.

A screenshot may show both channels simultaneously, but it is supporting evidence; it does not replace preserving the numerical CSV data for each channel.

## 3. Step 1 — inspect the CSV header before calculations

Before interpreting waveform values, record or verify:

- channel identity: CH1 or CH2;
- number of samples `N`;
- sample/time interval `Δt`;
- probe attenuation;
- frequency or automatic measurements if exported;
- peak-to-peak or RMS values if exported;
- file/configuration identity.

Do not infer the physical signal from the waveform shape alone.

## 4. Step 2 — derive acquisition properties

From the sample interval:

`fs = 1 / Δt`

where `fs` is the sampling rate.

For `N` samples:

`T ≈ N × Δt`

is the approximate captured record duration.

The Nyquist frequency is:

`fN = fs / 2`

For FFT work, the approximate frequency resolution of a record of duration `T` is:

`Δf = 1 / T`

These quantities shall be checked before concluding that a CSV can represent a requested frequency band.

## 5. Step 3 — compare acquisition conditions

Two files should only be directly compared when the intentionally changed variable is known and the important acquisition/test conditions are otherwise held constant.

Check, where applicable:

- same sample interval / sampling rate;
- same record length / sample count;
- same probe attenuation;
- same channel coupling;
- same generator frequency;
- same generator amplitude;
- same reference resistor;
- same wiring and grounding;
- same sensor supply;
- same FILTER configuration except for the capacitor intentionally under test.

If these differ, document the difference before interpreting amplitude changes as filter behavior.

## 6. Step 4 — interpret CH1 as the current reference

CH1 measures the voltage across the reference resistor:

`RREF = 68 Ω`

Ohm's law gives:

`I(t) = VCH1(t) / 68 Ω`

For peak-to-peak values:

`Ipp = VCH1,pp / 68 Ω`

For a centered sinusoid:

`Ipk = Ipp / 2`

and:

`Irms = Ipk / √2`

Example:

If:

`VCH1,pp = 1.14 V`

then:

`Ipp = 1.14 / 68 ≈ 16.8 mA p-p`

and for a zero-centered sine:

`Ipk ≈ 8.4 mA`.

CH1 is therefore the measured current reference. The function-generator amplitude setting alone shall not be treated as the actual primary current because the generator has non-zero source impedance and the complete circuit determines the delivered current.

## 7. Step 5 — verify the input before comparing filters

Before comparing ACS724 output between two FILTER configurations, compare CH1 first.

If CH1 amplitude remains approximately unchanged, the injected current is approximately unchanged and a CH2 change can reasonably be attributed to the sensor/filter configuration, subject to the other controls.

If CH1 changes significantly, the experiment no longer has a constant input. In that case, raw CH2 amplitudes shall not be compared directly; use the gain ratio described below.

## 8. Step 6 — interpret CH2 as ACS724 VOUT

CH2 measures ACS724 output voltage.

Conceptually:

`VOUT(t) = Voffset + VAC(t) + noise(t)`

The DC offset is required for absolute current conversion, but the dynamic frequency-response test is primarily interested in the AC component at the applied stimulus frequency.

The relevant AC amplitude may be obtained using a fitted sine, FFT component, or consistent oscilloscope amplitude measurement. Peak-to-peak values may also be used when the waveform is sufficiently sinusoidal and the same amplitude convention is used for both current and voltage.

Do not mix peak, peak-to-peak, and RMS quantities in one gain calculation.

## 9. Step 7 — calculate sensor transfer gain

For each frequency:

`G(f) = VOUT,AC / IAC`

Units are volts per ampere (`V/A`).

Use the same amplitude definition in numerator and denominator, e.g.:

`G(f) = VOUT,pp / Ipp`

or:

`G(f) = VOUT,rms / Irms`.

At sufficiently low frequency, measured gain should be reasonably consistent with the calibrated sensor sensitivity under the current test conditions. The current project calibration is approximately:

`S = 0.74472 V/A`.

This value is a useful sanity check, not a substitute for the dynamic measurement.

## 10. Step 8 — normalize for frequency-response comparison

Choose a low-frequency reference, for example 1 kHz if it is confirmed to be well inside the passband.

Normalize gain as:

`Hnorm(f) = G(f) / G(fref)`

Then convert to decibels:

`Gain_dB(f) = 20 log10(Hnorm(f))`

Interpretation:

- `Hnorm = 1` → `0 dB`;
- `Hnorm ≈ 0.891` → about `-1 dB`;
- `Hnorm = 0.707` → about `-3 dB`.

The measured -3 dB point estimates the effective filter bandwidth.

## 11. Step 9 — compare with the theoretical FILTER prediction

For the first-order ACS724 FILTER model:

`|H(f)| = 1 / sqrt(1 + (f/fc)^2)`

with:

`fc = 1 / (2πRFCtotal)`.

Measured normalized gain should be compared against this prediction at the same frequencies, especially at the formal project band edge of 10 kHz.

A disagreement is not automatically an error; it may indicate sensor internal dynamics, component tolerance, measurement uncertainty, stimulus limitations, coupling, or non-ideal circuit behavior.

## 12. Noise-file analysis

For zero-current FILTER noise measurements, remove the mean/DC level before calculating variation.

Useful quantities are:

- mean output;
- standard deviation / RMS-type variation after mean removal;
- peak-to-peak variation;
- FFT or spectral density when needed.

Equivalent current-domain RMS noise can be estimated using measured sensitivity:

`σI = σV / S`.

Peak-to-peak shall not be converted to RMS by a fixed factor unless the waveform/statistical distribution justifies it.

## 13. Minimum manual-analysis checklist

For every new CSV:

1. Read the header.
2. Identify CH1 or CH2.
3. Confirm what that channel was physically connected to.
4. Calculate/check `fs`, record duration, and Nyquist frequency.
5. Verify acquisition conditions against the comparison file.
6. For CH1, convert resistor voltage to current using `I = V/68 Ω`.
7. For CH2, isolate the AC sensor response from DC offset and noise.
8. Confirm the input current remained comparable.
9. Calculate `G(f) = VOUT,AC/IAC`.
10. Normalize to the low-frequency reference.
11. Convert normalized magnitude to dB.
12. Compare measured result with the theoretical filter prediction.
13. Record limitations rather than forcing agreement.

## 14. Interpretation rule

The CSV is evidence of sampled voltage versus time for the channel named in its header. The meaning of that voltage comes from the documented wiring. Therefore quantitative analysis shall always maintain the chain:

`CSV header -> physical channel mapping -> acquisition validation -> electrical conversion -> normalized comparison -> engineering conclusion`.

This prevents a channel-label mistake from becoming a false electrical conclusion.

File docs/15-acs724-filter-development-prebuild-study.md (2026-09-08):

# Phase 3 Extension — ACS724 FILTER Development: Theory, Prediction, and Pre-Build Record

**Status:** UNDERSTAND + PREDICT complete; BUILD not started  
**Project:** Actuator Health Monitoring System  
**Date:** 2026-09-08

## Purpose

This document records the theory, calculations, engineering interpretation, and pre-build decisions established before modifying the ACS724 FILTER network.

The project workflow remains:

`understand -> design -> predict -> build -> measure -> validate -> document`

This record intentionally stops before the build step. No external FILTER capacitor has yet been accepted as the final Rev-1 design value.

The formal diagnostic signal band remains:

`DC to 10 kHz`

The objective of the FILTER-development phase is therefore not to make the oscilloscope trace as smooth as possible. The objective is to reduce unnecessary broadband output noise while preserving diagnostically useful current information through 10 kHz with a known amplitude, phase, and transient-response tradeoff.

---

## 1. Experimental context entering FILTER development

The preceding zero-current noise-isolation work established the following bench observations:

- repeatable zero-current ACS724 `VOUT` disturbance of approximately `29.55 mV RMS` under the tested configuration;
- oscilloscope/probe floor approximately `1.43 mV RMS`, much smaller than the observed sensor-output disturbance;
- motor physically removed during the decisive zero-current noise tests;
- bench-supply versus Arduino-supply A-B-A comparison changed measured `VCC` noise substantially while `VOUT` noise remained near 30 mV RMS;
- the 20 MHz oscilloscope bandwidth limiter reduced measured high-frequency `VCC` noise as expected;
- the approximately 30 mV RMS `VOUT` disturbance is therefore real and repeatable in the present bench configuration, but it has **not** been proven to be purely intrinsic ACS724 IC noise.

Remaining possible contributors include the sensor itself, its FILTER network, carrier layout, output-node coupling, grounding/local coupling, and other analog implementation effects.

This motivates a controlled FILTER-capacitance experiment.

---

## 2. ACS724 FILTER-node model

For filter-development calculations, the relevant ACS724 signal-conditioning section is modeled as an internal resistance feeding the FILTER node, with capacitance from FILTER to ground:

```text
internal signal
     |
     R_F(int) ~= 1.8 kOhm
     |
     +-------> buffered internal/output path -> VOUT
     |
     C_F
     |
    GND
```

The Pololu #4048 carrier already includes approximately:

`C_stock = 1 nF`

from FILTER to ground.

The simple first-order design model therefore uses:

`R_F = 1.8 kOhm`

and

`C_total = C_stock + C_ext`

where `C_ext` is any additional capacitor intentionally placed between FILTER and GND.

Because parallel capacitors add:

`C_total = 1 nF + C_ext`

The stock `1 nF` carrier configuration gives a simple RC prediction near `88.4 kHz`, consistent with the carrier's approximate `90 kHz` bandwidth statement. This agreement is used as a useful sanity check for candidate calculations.

The RC model is a design approximation. The complete IC has additional internal dynamics, so final bandwidth shall be established by measurement rather than calculation alone.

---

## 3. Capacitor polarity and selected component type

The available candidate capacitors are small ceramic capacitors:

- `2.2 nF`, marking `222`;
- `3.3 nF`, marking `332`;
- `4.7 nF`, marking `472`.

These ceramic capacitors are **non-polarized**. Either lead may be connected to FILTER or GND.

A polarized capacitor has designated positive and negative terminals and must normally be installed with the correct DC polarity. Electrolytic and many tantalum capacitors are common polarized examples. Their construction enables relatively large capacitance in a compact package, but reverse connection can cause leakage, damage, heating, or failure.

The ACS724 FILTER candidates in this study do not require a polarized capacitor. A small ceramic capacitor is appropriate for this low-capacitance, high-frequency filtering function.

---

## 4. RC circuit voltages, current, and impedance

For a sinusoidal source applied to a series RC low-pass:

```text
Vin ---- R ----+---- Vout = V_C
               |
               C
               |
              GND
```

The resistor impedance is:

`Z_R = R`

The capacitor impedance is:

`Z_C = 1 / (j omega C)`

with:

`omega = 2 pi f`

The same series current flows through the resistor and capacitor:

`I = Vin / (R + Z_C)`

The component voltages are:

`V_R = I R`

`V_C = I Z_C`

Kirchhoff's voltage law remains:

`Vin = V_R + V_C`

However, for AC sinusoidal steady state this is a **phasor** sum. `V_R` and `V_C` do not generally have the same phase, so their magnitudes must not simply be added arithmetically.

For an ideal series RC circuit, resistor voltage is in phase with current while capacitor voltage lags current by 90 degrees. The input phasor is the vector sum of those two component-voltage phasors.

---

## 5. First-order RC low-pass transfer function

The low-pass output is the capacitor voltage. Using the impedance-divider relation:

`H(j omega) = Vout / Vin = Z_C / (R + Z_C)`

Substituting:

`Z_C = 1 / (j omega C)`

gives:

`H(j omega) = 1 / (1 + j omega R C)`

This is the canonical first-order RC low-pass transfer function.

Its magnitude is:

`|H| = 1 / sqrt(1 + (omega R C)^2)`

or, using cutoff frequency:

`|H(f)| = 1 / sqrt(1 + (f / f_c)^2)`

The phase is:

`phi(f) = -atan(f / f_c)`

The cutoff frequency is:

`f_c = 1 / (2 pi R C)`

At `f = f_c`:

- amplitude ratio = `1 / sqrt(2) = 0.707`;
- attenuation = approximately `-3.01 dB`;
- phase = `-45 degrees`.

Important interpretation: setting `f_c = 10 kHz` would mean a genuine 10 kHz diagnostic component is already reduced to about 70.7% of its low-frequency amplitude. Therefore the desired diagnostic-band edge and the filter's -3 dB cutoff shall not automatically be treated as the same frequency.

---

## 6. Frequency-domain physical interpretation

Capacitor impedance magnitude is:

`|Z_C| = 1 / (2 pi f C)`

Therefore:

- at low frequency, capacitor impedance is large and the signal is weakly shunted to ground;
- at high frequency, capacitor impedance becomes smaller and more high-frequency content is diverted toward ground;
- increasing capacitance reduces capacitor impedance at any given nonzero frequency and therefore lowers the filter bandwidth.

Thus:

`C up -> f_c down -> stronger high-frequency attenuation`

The same filtering applies to high-frequency noise components as to high-frequency deterministic signals.

---

## 7. Noise fundamentals

### 7.1 Random noise adds by power, not direct voltage magnitude

Independent random RMS noise contributions combine by root-sum-square:

`V_total = sqrt(V_1^2 + V_2^2 + ...)`

This is why broadband RMS noise does not scale linearly with bandwidth.

### 7.2 White-noise density

For approximately flat voltage-noise density:

`e_n [V/sqrt(Hz)]`

integrated RMS noise over an ideal rectangular bandwidth `B` is:

`V_n,rms = e_n sqrt(B)`

Therefore:

`V_n,rms proportional to sqrt(B)`

Examples of the scaling law:

- bandwidth reduced by factor 2 -> RMS noise reduced by `sqrt(2)`;
- bandwidth reduced by factor 4 -> RMS noise reduced by factor 2;
- bandwidth reduced by factor 9 -> RMS noise reduced by factor 3.

This square-root relationship applies under the white-noise and independent-random-process assumptions.

---

## 8. Equivalent Noise Bandwidth of a first-order RC filter

For deterministic signal amplitude, the filter transfer magnitude is:

`|H(f)| = 1 / sqrt(1 + (f/f_c)^2)`

Noise power is proportional to voltage squared, so the power-transfer function is:

`|H(f)|^2 = 1 / (1 + (f/f_c)^2)`

For flat input noise power spectral density `S_0`, total output noise power is:

`V_n,rms^2 = S_0 integral_0^infinity |H(f)|^2 df`

Substitute:

`|H(f)|^2 = 1 / (1 + (f/f_c)^2)`

Let:

`x = f / f_c`

so:

`df = f_c dx`

Then:

`V_n,rms^2 = S_0 f_c integral_0^infinity 1/(1+x^2) dx`

Because:

`integral 1/(1+x^2) dx = atan(x)`

and:

`atan(infinity) - atan(0) = pi/2`

we obtain:

`V_n,rms^2 = S_0 (pi/2) f_c`

Therefore the first-order RC equivalent noise bandwidth is:

`ENBW = (pi/2) f_c`

or:

`ENBW ~= 1.571 f_c`

This does **not** mean signals are passed flat to `1.571 f_c`. ENBW is the width of an ideal rectangular filter that would pass the same total white-noise power as the real RC filter.

The reason `ENBW > f_c` is that a first-order RC does not stop transmission abruptly at `f_c`; frequencies above cutoff still contribute progressively attenuated noise power.

For flat voltage-noise density:

`V_n,rms = e_n sqrt((pi/2) f_c)`

---

## 9. Time-domain transient response of the same first-order low-pass

The frequency-domain and time-domain descriptions represent the same physical system.

The RC time constant is:

`tau = R C`

Because:

`f_c = 1 / (2 pi R C)`

we also have:

`tau = 1 / (2 pi f_c)`

Thus bandwidth and transient speed are directly linked:

- higher bandwidth -> smaller `tau` -> faster response;
- lower bandwidth -> larger `tau` -> slower response.

### 9.1 Step response for an initially uncharged capacitor

For a step from `0 V` to `V_S` at `t = 0`:

`V_C(t) = V_S (1 - exp(-t/tau))`

`I_C(t) = (V_S/R) exp(-t/tau)`

`V_R(t) = V_S exp(-t/tau)`

At the instant immediately after the step:

- capacitor voltage cannot jump instantaneously;
- for an initially uncharged capacitor, `V_C(0+) = 0`;
- the capacitor can therefore be approximated as a short circuit **only at that initial instant for this specific zero-initial-voltage step case**;
- current is maximum: `I_C(0+) = V_S/R`.

At DC steady state:

- capacitor current tends to zero;
- capacitor voltage tends to `V_S`;
- the capacitor is approximated as an open circuit for steady DC.

### 9.2 Settling percentages

For the charging step:

| Time | Capacitor voltage relative to final value | Current relative to initial value |
|---|---:|---:|
| `0` | 0% | 100% |
| `1 tau` | 63.2% | 36.8% |
| `2 tau` | 86.5% | 13.5% |
| `3 tau` | 95.0% | 5.0% |
| `4 tau` | 98.2% | 1.83% |
| `5 tau` | 99.33% | 0.67% |

The phrase "fully charged at 5 tau" is therefore an engineering approximation. At `5 tau` the response has reached approximately 99.3% of its final value, not mathematically 100%.

### 9.3 General capacitor-voltage continuity rule

A capacitor voltage cannot change instantaneously under finite current:

`V_C(0+) = V_C(0-)`

For more general first-order transitions:

`V_C(t) = V_final + (V_initial - V_final) exp(-t/tau)`

This form is preferred when the capacitor is not initially uncharged.

---

## 10. Stock FILTER prediction

Using:

`R_F = 1.8 kOhm`

`C_total = 1.0 nF`

we obtain:

`tau = 1.80 us`

`f_c = 88.42 kHz`

`ENBW = 138.89 kHz`

Approximate 99.3% settling time:

`5 tau = 9.0 us`

At 10 kHz:

- amplitude ratio = `0.9937`;
- amplitude remaining = `99.37%`;
- attenuation = `-0.055 dB`;
- phase = `-6.45 degrees`.

This confirms that the stock FILTER configuration has little effect on the formal 10 kHz diagnostic-band edge.

---

## 11. Candidate FILTER predictions

### 11.1 Candidate A — 2.2 nF external

Total capacitance:

`C_total = 1.0 nF + 2.2 nF = 3.2 nF`

Predicted values:

- `tau = 5.76 us`;
- `f_c = 27.63 kHz`;
- `ENBW = 43.40 kHz`;
- `5 tau = 28.8 us`.

At 10 kHz:

- amplitude ratio = `0.9403`;
- amplitude remaining = `94.03%`;
- attenuation = `-0.535 dB`;
- phase = `-19.90 degrees`.

Using the measured baseline `29.55 mV RMS` and assuming the reducible portion behaves as broadband white noise governed by this bandwidth change:

`V_n,new / V_n,stock = sqrt(f_c,new / f_c,stock)`

Predicted RMS noise:

`29.55 mV -> approximately 16.52 mV RMS`

This is the **conservative candidate**: strong theoretical noise reduction with relatively small 10 kHz amplitude loss.

### 11.2 Candidate B — 3.3 nF external

Total capacitance:

`C_total = 1.0 nF + 3.3 nF = 4.3 nF`

Predicted values:

- `tau = 7.74 us`;
- `f_c = 20.56 kHz`;
- `ENBW = 32.30 kHz`;
- `5 tau = 38.7 us`.

At 10 kHz:

- amplitude ratio = `0.8993`;
- amplitude remaining = `89.93%`;
- attenuation = `-0.922 dB`;
- phase = `-25.93 degrees`.

White-noise-only prediction from the measured `29.55 mV RMS` baseline:

`29.55 mV -> approximately 14.25 mV RMS`

This is the **more aggressive candidate**: lower theoretical noise than 2.2 nF, but with greater 10 kHz amplitude and phase impact and a slower transient response.

### 11.3 Candidate C — 4.7 nF external

Total capacitance:

`C_total = 1.0 nF + 4.7 nF = 5.7 nF`

Predicted values:

- `tau = 10.26 us`;
- `f_c = 15.51 kHz`;
- `ENBW = 24.37 kHz`;
- `5 tau = 51.3 us`.

At 10 kHz:

- amplitude ratio = `0.8405`;
- amplitude remaining = `84.05%`;
- attenuation = `-1.509 dB`;
- phase = `-32.81 degrees`.

White-noise-only prediction from the measured `29.55 mV RMS` baseline:

`29.55 mV -> approximately 12.38 mV RMS`

This candidate appears increasingly aggressive for a system whose formal diagnostic band extends to 10 kHz.

---

## 12. Consolidated candidate comparison

| External C | Total C | Predicted `f_c` | `tau` | `5 tau` | Gain @ 10 kHz | Loss @ 10 kHz | Phase @ 10 kHz | ENBW | Predicted RMS noise* |
|---:|---:|---:|---:|---:|---:|---:|---:|---:|---:|
| 0 nF | 1.0 nF | 88.42 kHz | 1.80 us | 9.0 us | 99.37% | -0.055 dB | -6.45 deg | 138.89 kHz | 29.55 mV |
| **2.2 nF** | **3.2 nF** | **27.63 kHz** | **5.76 us** | **28.8 us** | **94.03%** | **-0.535 dB** | **-19.90 deg** | **43.40 kHz** | **16.52 mV** |
| **3.3 nF** | **4.3 nF** | **20.56 kHz** | **7.74 us** | **38.7 us** | **89.93%** | **-0.922 dB** | **-25.93 deg** | **32.30 kHz** | **14.25 mV** |
| 4.7 nF | 5.7 nF | 15.51 kHz | 10.26 us | 51.3 us | 84.05% | -1.509 dB | -32.81 deg | 24.37 kHz | 12.38 mV |

`*` Predicted RMS noise assumes the measured baseline disturbance is dominated by flat broadband noise shaped by the FILTER bandwidth. This is a hypothesis to be tested, not an established sensor specification.

---

## 13. Engineering interpretation of the tradeoff

The filter-design problem is multi-dimensional. Lowering bandwidth gives potential noise improvement but simultaneously causes:

1. greater attenuation near the 10 kHz diagnostic-band edge;
2. greater phase lag near the upper diagnostic band;
3. slower transient response and more smearing of sharp current changes.

The predicted returns also diminish as capacitance is increased.

Moving from 2.2 nF to 3.3 nF changes the white-noise prediction from approximately:

`16.52 mV -> 14.25 mV RMS`

while 10 kHz amplitude changes from:

`94.03% -> 89.93%`

Moving further from 3.3 nF to 4.7 nF only improves the white-noise prediction to approximately:

`12.38 mV RMS`

while reducing the 10 kHz amplitude further to:

`84.05%`

Thus the current pre-build interpretation is:

- `2.2 nF` = best conservative candidate;
- `3.3 nF` = best aggressive candidate;
- `4.7 nF` = useful comparison point but likely unnecessarily aggressive for the current DC-to-10-kHz requirement.

No final FILTER capacitor value is approved before measurement.

---

## 14. Transient interpretation for actuator-current signals

A real current step contains very high-frequency spectral content. A low-pass filter cannot reproduce an ideal vertical edge.

For the `3.3 nF` external candidate (`tau = 7.74 us`), a step response reaches approximately:

- 63.2% after `7.74 us`;
- 86.5% after `15.48 us`;
- 95.0% after `23.22 us`;
- 98.2% after `30.96 us`;
- 99.33% after `38.7 us`.

For the `2.2 nF` external candidate (`tau = 5.76 us`), approximate 99.3% settling occurs after `28.8 us`.

This is the time-domain expression of the same bandwidth tradeoff seen in the Bode response.

Later health-monitoring algorithms may use not only spectral amplitude but also startup or switching transients. Therefore time-domain distortion shall be considered when selecting the final sensor FILTER setting.

---

## 15. Important distinction: sensor FILTER versus final anti-alias filter

Changing the ACS724 FILTER capacitor is **not** equivalent to completing the system anti-alias design.

The sensor FILTER experiment answers:

> How much sensor/output-chain noise reduction can be obtained while preserving the required diagnostic information?

The complete acquisition design still requires coordinated selection of:

`sensor bandwidth -> analog front end -> anti-alias filter -> ADC sample rate`

The existing Rev-1 architecture targets `100 kS/s` ADC acquisition. Deliberate system-level anti-alias filtering remains a later AFE responsibility.

The ACS724 FILTER network is therefore an upstream bandwidth/noise optimization mechanism, not automatically the final anti-alias solution.

---

## 16. Pre-build wiring definition

For the upcoming zero-current FILTER experiment:

- ACS724 carrier powered from bench supply at nominal `5.00 V`;
- oscilloscope probe tip connected to `VOUT`;
- oscilloscope ground connected to sensor `GND`;
- motor disconnected;
- primary current terminals `IP+` and `IP-` left without a current path so `I_P = 0 A`;
- Arduino disconnected;
- external ceramic capacitor connected directly between the carrier's FILTER pad and nearby GND pad;
- capacitor leads kept as short as practical;
- power removed before inserting or changing the capacitor.

The external capacitor is in parallel with the stock 1 nF carrier capacitor.

---

## 17. Build/measure sequence approved for the next step

The first hardware sequence shall preserve all practical setup variables except external FILTER capacitance:

`Stock -> 2.2 nF external -> 3.3 nF external -> Stock`

The final Stock step is an A2-style return control to detect drift or accidental setup changes.

For each state, the intended measurements include:

- mean `VOUT`;
- RMS / standard deviation after mean removal;
- peak-to-peak as supporting information;
- FFT / spectral evidence;
- acquisition sample rate and duration;
- oscilloscope bandwidth setting;
- relevant VCC and wiring state.

The 10 kS/s, 1-second acquisition previously used for low-frequency motor spectra has Nyquist frequency only 5 kHz and therefore cannot characterize a 15-90 kHz FILTER response. A separate higher-sample-rate capture is required for FILTER bandwidth/noise characterization.

A practical target for the higher-bandwidth capture is approximately `>= 500 kS/s`, preferably around `1 MS/s` where the instrument/data path permits.

The existing 10 kS/s capture may still be retained as a secondary low-frequency FFT view.

---

## 18. Hypotheses to be tested during BUILD/MEASURE

### H1 — FILTER capacitance controls a meaningful part of the observed zero-current disturbance

If the approximately 30 mV RMS output disturbance contains a substantial broadband component shaped by the sensor FILTER bandwidth, adding 2.2 nF or 3.3 nF should reduce measured RMS noise significantly and the Stock return condition should move back toward the original baseline.

### H2 — White-noise square-root bandwidth prediction is only approximate

The idealized predictions of approximately:

- `16.52 mV RMS` for 2.2 nF external;
- `14.25 mV RMS` for 3.3 nF external;
- `12.38 mV RMS` for 4.7 nF external;

are not acceptance criteria. Deviations are expected if the measured disturbance contains low-frequency interference, 1/f noise, discrete spectral lines, coupling, instrument contributions, or other non-white processes.

### H3 — 2.2 nF and 3.3 nF are the most relevant candidates

The likely engineering trade is expected to lie between:

- 2.2 nF external: more conservative preservation of the 10 kHz band;
- 3.3 nF external: stronger noise reduction with larger upper-band amplitude/phase impact.

The experiment shall determine whether the additional noise benefit of 3.3 nF justifies its larger signal/transient penalty.

---

## 19. Decision gate after measurement

A final external FILTER value shall only be selected after comparing measured:

1. zero-current RMS noise reduction;
2. spectral-noise change;
3. measured or verified amplitude response through 10 kHz;
4. phase behavior where relevant;
5. transient-response implications;
6. repeatability of the Stock -> candidate -> Stock control sequence.

The final decision shall be based on the required diagnostic information content, not appearance of the oscilloscope trace.

---

## 20. Current project state

Completed before build:

- RC low-pass physical interpretation;
- capacitor impedance and AC current/voltage relationships;
- transfer-function derivation;
- cutoff, magnitude, and phase relationships;
- white-noise bandwidth scaling;
- root-sum-square noise interpretation;
- first-order RC ENBW derivation;
- transient step-response equations;
- time constant and settling interpretation;
- stock, 2.2 nF, 3.3 nF, and 4.7 nF quantitative predictions;
- candidate tradeoff assessment;
- intended zero-current build topology and controlled test sequence.

Next state:

`BUILD -> MEASURE -> VALIDATE`

No final additional ACS724 FILTER capacitance is yet accepted into the Rev-1 design baseline.

---

## References

- Allegro MicroSystems, ACS724/ACS725 current sensor datasheet.
- Pololu #4048 ACS724LLCTR-05AU current sensor carrier documentation.
- Existing project document: `docs/03-acs724-sensor-characterization.md`.
- Existing project evidence: `docs/evidence/acs724-zero-current-noise-isolation-2026-09-07.md`.

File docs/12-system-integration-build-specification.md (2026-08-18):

# Phase 12 — System Integration, Wiring, BOM and Build Specification

**Status:** Design complete / ready for PR review  
**Project:** Actuator Health Monitoring System

## Purpose

Phase 12 converts the accepted subsystem designs from Phases 1–11 into one coherent, buildable Rev-1 specification. Physical implementation, firmware coding, calibration and laboratory verification remain after design freeze.

## Accepted design baseline entering Phase 12

- Rev-1 actuator/motor: **≤24 V DC** laboratory operation.
- Calibrated current range: **0–5 A**, unidirectional.
- Current sensor: **Pololu #4048 / ACS724LLCTR-05AU**.
- Diagnostic band: **DC–10 kHz**; deterministic ADC baseline: **100 kS/s**.
- MCU: **Arduino UNO R4 WiFi / Renesas RA4M1**.
- AFE: **MCP6022-I/P**, approximately unity gain.
- System accuracy after calibration: **≤ ±0.10 A**, stretch **±0.05 A**.
- Reported-current resolution: **≤10 mA**.
- USB serial is the Rev-1 PC/MATLAB interface.
- Automatic motor shutdown is not part of Rev-1; bench-PSU current limiting is the initial active motor-current protection.
- Rev-1 hobby hardware shall never be connected directly to industrial mains or a 400 V motor circuit.

## 12.1 — Integrated Rev-1 topology and physical partitioning

### INT-001 — Four-region integrated system topology

**Status:** Accepted

Rev-1 is partitioned into actuator/high-current, analog measurement, digital/processing and host regions.

`motor current → ACS724 → VOUT → AFE/anti-alias filter → ADC → MCU → USB → PC/MATLAB`

## 12.2 — Actuator current-path wiring architecture

### INT-002 — Dedicated high-side sensor current path with fixed polarity convention

**Status:** Accepted

`bench PSU (+) → ACS724 IP+ → ACS724 IP− → motor (+) → motor (−) → bench PSU (−)`

Dedicated current-rated conductors/connectors shall be used; no motor current through solderless breadboard, MCU header wiring or measurement-ground conductors.

## 12.3 — Measurement-electronics power distribution

### INT-003 — UNO-derived coherent 5 V measurement domain

**Status:** Accepted

`USB-C → UNO R4 WiFi → UNO +5 V header → ACS724 VCC + MCP6022 VDD`, with common `GND_MEAS`. Motor power remains on the separate bench-PSU path. Actual measurement rail is characterized rather than assumed exactly 5.000 V.

## 12.4 — Ground/reference and laboratory-instrument architecture

### INT-004 — Common measurement ground with designated analog test points

**Status:** Accepted

`GND_MEAS = GND_UNO = GND_AFE = GND_ACS724-secondary`

Required test points: `TP_GND`, `TP_5V`, `TP_SENSOR`, `TP_AFE`. Instrument grounds shall not be assumed floating; ordinary probe grounds shall not be casually connected to actuator-current nodes.

## 12.5 — ACS724 secondary-side interface

### INT-005 — Direct sensor-to-AFE interface with stock FILTER and local decoupling

**Status:** Accepted

`5V_MEAS → ACS724 VCC`; `GND_MEAS → ACS724 GND`; `ACS724 VOUT → TP_SENSOR → AFE`.

Stock **1 nF FILTER** remains unchanged. Add **100 nF** local VCC-GND bypass capacitance.

## 12.6 — AFE implementation and component-value freeze

### INT-006A — Unity-gain Sallen-Key section realization

**Status:** Accepted

Two cascaded unity-gain Sallen-Key low-pass sections implement the fourth-order Butterworth response.

### INT-006B — Standard component values and nominal response

**Status:** Accepted

| Section | R1 | R2 | C1 | C2 | Nominal f0 | Nominal Q |
| --- | ---: | ---: | ---: | ---: | ---: | ---: |
| Low-Q | 9.76 kΩ | 9.76 kΩ | 1.2 nF | 1.0 nF | ≈14.89 kHz | ≈0.548 |
| High-Q | 4.07 kΩ | 4.07 kΩ | 6.8 nF | 1.0 nF | ≈15.00 kHz | ≈1.304 |

Use **1% resistors** and preferably **≤5% capacitors**. Nominal response: approximately −0.124 dB at 10 kHz, −2.99 dB at 15 kHz and −41.9 dB at 50 kHz.

### INT-006C — MCP6022 channel allocation, supply and decoupling

**Status:** Accepted

`ACS724 VOUT → low-Q channel A → high-Q channel B → TP_AFE → ADC`.

`VDD → 5V_MEAS`, `VSS → GND_MEAS`; **100 nF** local IC bypass plus **10 µF** AFE reservoir capacitance.

### INT-006D — Complete MCP6022 PDIP-8 net-level AFE circuit and headroom

**Status:** Accepted

| Pin | Function | Rev-1 connection |
| ---: | --- | --- |
| 1 | OUTA | low-Q output / high-Q input source |
| 2 | IN−A | tied to pin 1 |
| 3 | IN+A | low-Q `N2A` |
| 4 | VSS | `GND_MEAS` |
| 5 | IN+B | high-Q `N2B` |
| 6 | IN−B | tied to pin 7 |
| 7 | OUTB | `TP_AFE` / ADC source |
| 8 | VDD | `5V_MEAS` |

Low-Q: `TP_SENSOR → 9.76k → N1A → 9.76k → N2A → pin3`; `N2A → 1.0nF → GND`; `N1A → 1.2nF → pin1`; `pin1 → pin2`.

High-Q: `pin1 → 4.07k → N1B → 4.07k → N2B → pin5`; `N2B → 1.0nF → GND`; `N1B → 6.8nF → pin7`; `pin7 → pin6`; `pin7 → TP_AFE`.

Nominal valid 0.5–4.5 V span leaves approximately 0.5 V rail headroom; no level shift/attenuation required. Actual headroom is verified in Stage B.

## 12.7 — ADC interface and input protection

### INT-007 — Dedicated A0 interface with series isolation and local sampling capacitor

**Status:** Accepted

The Rev-1 AFE-to-ADC interface shall be:

`TP_AFE → 1 kΩ series resistor → ADC_IN / UNO A0`

with a **100 pF capacitor from the ADC-side A0 node to `GND_MEAS`**.

The local RC pole is approximately:

`fc = 1 / (2π × 1 kΩ × 100 pF) ≈ 1.59 MHz`

This network is therefore not an additional anti-alias filter and has negligible intended effect on the accepted DC–10 kHz diagnostic band. The 1 kΩ resistor provides source isolation and limits transient current into the ADC input; the 100 pF capacitor provides local charge support for the ADC sample-and-hold interface.

UNO **A0 is dedicated to the Rev-1 current-monitoring ADC signal**. The RA4M1 ADC shall be configured during Stage B with sampling/acquisition time sufficient to settle through the accepted source/interface network while maintaining the required deterministic **100 kS/s** sample rate.

No external Schottky clamp diodes are included in the baseline Rev-1 ADC interface. Under normal operation the MCP6022 output and RA4M1 ADC share the same approximately 5 V measurement domain, while the valid signal is nominally approximately **0.5–4.5 V**. Additional clamp devices would add leakage/capacitance to the precision measurement node without providing credible protection against a gross 24 V misconnection.

Approaching or reaching the ADC rails shall be treated as clipping/overrange and shall not be interpreted as a calibrated current value. Accidental connection of the 24 V actuator rail to A0 is explicitly **outside the Rev-1 ADC protection capability** and is prevented by the physical/wiring segregation rules rather than by this small-signal interface network.

Stage B verification shall demonstrate:

- correct ADC settling at 100 kS/s;
- no meaningful passband degradation from the interface network;
- no clipping throughout the intended valid 0.5–4.5 V AFE span;
- effective ADC-domain voltage resolution of **≤2 mV** under actual acquisition conditions.

### Rationale

A small series resistor and local capacitor provide practical ADC-drive isolation without burdening the precision analog path or duplicating the deliberately designed 15 kHz anti-alias filter. Avoiding unnecessary clamps preserves low leakage/capacitance while keeping the system boundary explicit: the ADC interface is protected for intended low-voltage analog operation, not arbitrary actuator-rail miswiring.

## 12.8 — MCU I/O and resource allocation

### INT-008 — Minimal dedicated acquisition-resource reservation

**Status:** Accepted

Reserve UNO **A0**, one ADC channel, one hardware timer for deterministic **100 kS/s**, one DMA/DTC-class transfer resource, and the USB/native serial path. Other MCU resources remain uncommitted unless required later.

## 12.9 — USB/PC physical and logical integration boundary

### INT-009 — Asynchronous USB host interface independent of real-time monitoring

**Status:** Accepted

UNO R4 WiFi USB-C is the sole baseline host interface. It supports normal telemetry, requested waveform capture and configuration/calibration exchange. USB/PC timing shall not control deterministic ADC sampling or real-time diagnostics.

## 12.10 — Protection implementation

### INT-010 — Layered motor, electronics and measurement-validity protection

**Status:** Accepted

The actuator-current path is:

`bench PSU (+) → series fuse → ACS724 IP+ → ACS724 IP− → motor → bench PSU (−)`

The bench PSU adjustable current limit is the primary active motor-current protection. A replaceable series fuse near PSU+ provides passive backup. The exact fuse rating remains a Stage B selection after safe motor-current characterization; it is not chosen merely from the 5 A measurement range.

Software/diagnostics distinguish overrange/invalid measurement from electrical damage. **5 A is the calibrated measurement-validity boundary, not automatically a hardware survival, fuse or shutdown threshold.**

## 12.11 — Rev-1 motor/actuator selection

### INT-011 — Philips/Saeco 24 VDC brew-group gearmotor selected as Rev-1 actuator

**Status:** Accepted

The Rev-1 actuator is the available **Philips/Saeco 24 VDC brew-group gearmotor** recovered from the user's failed coffee machine.

Motor-specific no-load, normal-load, startup/inrush and stall/jam currents remain **TBD — measure during Stage B implementation/verification**. Normal/intended tests should remain within the 0–5 A calibrated range wherever practical; any excursion above 5 A is treated as measurement overrange and constrained by PSU current limiting.

## 12.12 — Rev-1 BOM and procurement status

### INT-012 — Build BOM classification and procurement baseline

**Status:** Accepted

Core available hardware: UNO R4 WiFi, Pololu #4048 ACS724-05AU, MCP6022-I/P, Philips/Saeco 24 V gearmotor, Jesverty SPS-3010V, HANMATEK DOS1102S, and general passive-component assortments.

Required/verify procurement includes: 9.76 kΩ 1% ×2; 4.07 kΩ 1% ×2; controlled-tolerance 1.0 nF ×2, 1.2 nF ×1, 6.8 nF ×1; **1 kΩ resistor ×1; 100 pF capacitor ×1** for the ADC interface; 10 µF reservoir if absent; current-rated wire/connectors; inline fuse holder; low-current hookup wire as needed; prototype construction hardware as needed.

Filter resistors shall be **1% metal-film**. Filter capacitors should preferably be **C0G/NP0** or another stable controlled-tolerance dielectric. Exact fuse rating is selected after safe Stage B motor-current characterization.

## 12.13 — Wiring/interconnect specification

### INT-013 — 18 AWG motor-current harness with segregated low-level wiring

**Status:** Accepted

The complete Rev-1 motor-current path shall use **18 AWG stranded insulated copper conductors** as the baseline harness specification:

`PSU+ → inline fuse holder → ACS724 IP+ → ACS724 IP− → polarized motor connection → motor → PSU−`

The ACS724 primary-path pigtails shall be soldered directly into the carrier's high-current connection holes unless an equally suitable mechanically secure current-rated termination is deliberately selected during assembly. The pigtails shall be strain relieved so cable movement and connector forces are not transferred directly to the sensor PCB.

Where a detachable motor/PSU interconnect is required, use a **polarized two-conductor connector rated at least 10 A and 30 VDC**. The existing Philips/Saeco motor connector may be reused only if its current/voltage/mechanical condition can be verified suitable; otherwise replace it with a connector meeting the accepted rating.

The inline fuse holder shall be located in the positive actuator-supply path close to the PSU-side connection where practical. Its wiring and contact rating shall be at least consistent with the selected 18 AWG harness and Rev-1 current envelope. The fuse value itself remains TBD until Stage B motor characterization.

Low-current measurement-electronics connections (`5V_MEAS`, `GND_MEAS`, sensor VOUT, AFE nets, ADC signal) shall use ordinary suitable **22–24 AWG hookup/jumper wiring** or equivalent board interconnect. These conductors shall not be used in the motor-current path.

Analog/signal wiring shall be kept short and separated from the motor/high-current harness where practical. Long parallel routing between sensitive analog lines and motor-current conductors shall be avoided.

The build shall use an unambiguous polarity/color convention. Baseline convention:

- red high-current conductor: actuator `PSU+ / +24 V` side;
- black high-current conductor: actuator return / `PSU−`;
- red low-current conductor: `5V_MEAS`;
- black low-current conductor: `GND_MEAS`;
- a distinct non-red/non-black color: analog signal nets.

Labels shall identify `PSU+`, `FUSE`, `IP+`, `IP−`, `MOTOR+`, `MOTOR−`, `PSU−`, `5V_MEAS`, `GND_MEAS`, `TP_SENSOR`, `TP_AFE` and `A0` where applicable.

Motor-current wiring, Dupont jumpers and analog hookup wire shall be treated as different interconnect classes and shall not be substituted for one another merely because a connector physically fits.

## 12.14 — Mechanical and assembly constraints

### INT-014 — Secure open laboratory prototype with physically controlled current and analog regions

**Status:** Accepted

Rev-1 shall be implemented as a **secure open laboratory prototype**. A finished product enclosure is not required for Rev-1, but the assembly shall be mechanically stable, electrically controlled and suitable for repeatable bench testing.

The **motor/high-current path shall not use a solderless breadboard**. The 18 AWG current harness, inline fuse holder, ACS724 primary path and motor connections shall use mechanically secure current-rated terminations. Current-path wiring shall be routed and restrained so accidental movement cannot pull conductors free or transfer excessive force into component PCBs.

The **ACS724 carrier shall be mechanically supported**. Its 18 AWG primary-current pigtails shall receive strain relief so repeated cable movement does not flex the carrier or its solder joints.

The **low-current AFE may initially be assembled on a solderless breadboard**. The AFE shall nevertheless be compact. If Stage B verification shows that breadboard parasitics, contact quality, noise pickup or mechanical instability prevent accepted performance, the AFE shall migrate to perfboard or another soldered prototype construction without changing the accepted circuit topology unless a formal design revision is required.

The analog measurement region shall be kept physically separated from the motor body and motor-current harness where practical. Test points `TP_GND`, `TP_5V`, `TP_SENSOR` and `TP_AFE` shall remain physically accessible without disturbing the high-current wiring.

## 12.15 — Configuration and build identity

### INT-015 — Versioned build/configuration identity for measurement traceability

**Status:** Accepted

Every meaningful Rev-1 engineering dataset, calibration/reference record and verification result shall be traceable to the system configuration that produced it.

`Build ID = (hardware revision, firmware revision, calibration ID, motor ID, configuration ID)`

At minimum, measurement/capture metadata shall identify hardware revision, firmware revision/Git commit, active calibration ID, motor ID, acquisition configuration ID, and diagnostic/reference identity where applicable.

A configuration/calibration change that can materially alter numerical interpretation or diagnostic results shall produce a new corresponding identity/version rather than silently reusing the previous identifier. Exact serialization/file naming remains Stage B implementation detail.

## 12.16 — Integration completeness review

### INT-016 — Rev-1 integration baseline complete

**Status:** Accepted

The Phase 12 integration review confirms that the accepted subsystem designs from Phases 1–11 have been reconciled into one coherent Rev-1 build specification with no remaining product-level interface, component, wiring, protection or configuration decision that blocks later implementation.

The integrated Rev-1 current path is:

`24 V bench PSU → series fuse → ACS724 primary path → Philips/Saeco 24 VDC gearmotor → PSU return`

The integrated measurement path is:

`ACS724 VOUT → fourth-order MCP6022 Butterworth AFE → 1 kΩ / 100 pF ADC interface → UNO R4 A0 / RA4M1 ADC → deterministic 100 kS/s acquisition → MCU processing/diagnostics → USB → PC/MATLAB`

The Phase 1 product requirements remain represented in the integrated design: 0–5 A calibrated current range, DC–10 kHz diagnostic band, 100 kS/s acquisition, ≤ ±0.10 A calibrated system-accuracy target, ≤10 mA reported-current resolution, startup/load/overload/stall characterization, and low-voltage ≤24 V laboratory operation.

The following remaining quantities are legitimate **implementation/verification TBDs** rather than missing design decisions:

- actual ACS724 zero-current offset, sensitivity, noise and residual calibration error;
- actual 5 V measurement rail/reference behavior;
- realized AFE gain, offset, frequency response and clipping margin;
- RA4M1 ADC effective resolution, settling and noise at 100 kS/s;
- motor no-load, representative load, startup/inrush and stall/jam currents;
- final overload/stall diagnostic thresholds and persistence values derived from characterization;
- final replaceable fuse rating selected after safe motor-current characterization;
- exact physical mounting/baseplate and other non-electrical implementation conveniences.

None of these values requires invention of a new product architecture before construction can begin. They shall be populated through Stage B/C implementation, calibration and verification as defined by DEV-001.

The integration review also corrected stale repository status/index information for earlier completed phases. Documentation status cleanup does not change their approved engineering content.

### Phase 12 handoff

Phase 12 provides Phase 13 with a concrete Rev-1 system to verify and Phase 14 with a complete integration baseline to review for design freeze.

Implementation shall **not** begin yet. Stage A continues with:

- Phase 13 — System Verification and Acceptance Plan;
- Phase 14 — Rev-1 Design Review and Design Freeze.

Only after the Phase 14 design freeze may Stage B physical implementation begin.

## Phase 12 completion criterion

The Phase 12 completion criterion is satisfied: another engineer can proceed toward the Rev-1 implementation after design freeze without inventing missing product-level wiring, component, interface or protection decisions.

**Phase 12 status: DESIGN COMPLETE / READY FOR PR REVIEW**

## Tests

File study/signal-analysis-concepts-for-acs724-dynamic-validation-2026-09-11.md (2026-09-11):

# Signal-analysis concepts used in ACS724 dynamic validation — 2026-09-11

**Project:** Actuator Health Monitoring System  
**Stage:** Stage B — ACS724 dynamic/FILTER validation  
**Purpose:** Study record explaining the mathematical and measurement concepts used to judge the 100 Hz baseline and later frequency-response points.

This document is intentionally educational. It does not change the frozen 100 Hz engineering decision. It explains how the quantities used in the Stage B evidence records are defined, calculated, interpreted, and limited.

---

## 1. Coherent sine fit used in the project

For a known test frequency `f0`, each captured channel is modeled as:

`v(t) = V0 + A*sin(2*pi*f0*t) + B*cos(2*pi*f0*t)`

where:

- `V0` is the DC/mean term;
- `A` is the fitted sine coefficient;
- `B` is the fitted cosine coefficient;
- `f0` is the commanded excitation frequency, for example 100 Hz;
- `t` is the CSV time vector.

The coefficients are found by least squares: choose `V0`, `A`, and `B` so that the sum of squared differences between the measured samples and the fitted model is as small as possible.

For each sample `i`:

`y_i = measured sample`

`yhat_i = V0 + A*sin(2*pi*f0*t_i) + B*cos(2*pi*f0*t_i)`

The residual is:

`r_i = y_i - yhat_i`

The coherent peak amplitude at `f0` is:

`Vpk = sqrt(A^2 + B^2)`

and therefore:

`Vpp = 2*sqrt(A^2 + B^2)`

This is why the project does not use raw oscilloscope `Vpp` for noisy ACS724 VIOUT measurements: raw peak-to-peak is dominated by the largest excursions, while the coherent fit extracts only the part that repeats exactly at the known excitation frequency.

---

## 2. What fit R^2 means

`R^2` is the coefficient of determination. It answers:

> How much of the measured sample-to-sample variation is explained by the fitted model?

Define:

`SSE = sum((y_i - yhat_i)^2)`

This is the residual sum of squares: variation not explained by the model.

Define:

`SST = sum((y_i - ybar)^2)`

where `ybar` is the mean of all samples. `SST` is the total measured variation around the mean.

Then:

`R^2 = 1 - SSE/SST`

Interpretation:

- `R^2 = 1`: the fitted DC + sine/cosine model explains the record perfectly;
- `R^2 = 0`: it explains no more variation than simply using the mean;
- values close to 1 indicate a very clean waveform at the modeled frequency;
- low `R^2` can occur even when a real coherent component exists, if that component is small compared with broadband noise or other unmodeled content.

### Project interpretation

CH1 across RREF at the stronger 100 Hz stimulus produced `R^2` values around 0.998–0.999. This means the RREF waveform is dominated by a clean 100 Hz sinusoid and is an excellent current reference.

CH2 at ACS724 VIOUT had a much lower fit quality because the wanted 100 Hz component was only a few millivolts while the waveform contained tens of millivolts RMS of broadband/unmodeled variation. A low CH2 `R^2` therefore does not automatically mean that the fitted 100 Hz component is fictitious; it means the 100 Hz sinusoid explains only a small fraction of the total CH2 variance.

Important limitation: `R^2` is a model-fit metric, not a direct signal-quality certification. A waveform can have high `R^2` but still be systematically wrong, clipped, incorrectly scaled, or measured from the wrong node.

---

## 3. Residual and residual RMS

After the fitted DC + target-frequency sinusoid is calculated, the residual is what remains:

`r_i = y_i - yhat_i`

The residual RMS is:

`RMS_residual = sqrt((1/N)*sum(r_i^2))`

where `N` is the number of samples.

This is the root-mean-square size of everything not explained by the chosen model.

### Physical meaning

Residual RMS may contain:

- broadband electrical noise;
- interference at other frequencies;
- harmonics of the test frequency;
- switching spikes;
- slow drift;
- oscilloscope quantization;
- measurement pickup;
- waveform distortion;
- model mismatch;
- any real signal content not included in the fit.

Therefore the phrase **residual noise** in the project is shorthand. Strictly, residual RMS is not guaranteed to be pure random noise. It is the RMS of the unmodeled remainder.

### Why RMS is used

Positive and negative residual samples would cancel if they were simply averaged. Squaring removes the sign, averaging measures mean energy-like magnitude, and the square root returns the result to volts.

For example, a CH2 residual RMS near 30 mV means that after removing the fitted DC and coherent 100 Hz sine, the remaining waveform has an RMS magnitude of about 30 mV.

That does **not** mean the sensor itself has exactly 30 mV RMS intrinsic noise. The value includes the whole measurement chain and all unmodeled content in that acquisition.

---

## 4. How phase is calculated from the sine fit

The fitted AC part is:

`A*sin(omega*t) + B*cos(omega*t)`

where:

`omega = 2*pi*f0`

Any single sinusoid can also be written as:

`C*sin(omega*t + phi)`

Using:

`sin(x + phi) = sin(x)*cos(phi) + cos(x)*sin(phi)`

we obtain:

`A = C*cos(phi)`

`B = C*sin(phi)`

therefore:

`C = sqrt(A^2 + B^2)`

and:

`phi = atan2(B, A)`

`atan2` is used rather than ordinary `atan(B/A)` because it preserves the correct quadrant and therefore the correct phase sign/range.

### Transfer phase between CH1 and CH2

Each channel gets its own fitted phase:

`phi_CH1 = atan2(B1, A1)`

`phi_CH2 = atan2(B2, A2)`

The sensor/output phase relative to the current reference is:

`Delta_phi = phi_CH2 - phi_CH1`

and then wrapped into a convenient interval such as `-180 deg ... +180 deg`.

### Critical condition

Phase comparison is meaningful only if both channels represent the same acquisition time reference. That is why the project freezes one acquisition and exports CH1 and CH2 without resuming acquisition.

If CH1 and CH2 came from unrelated acquisitions with arbitrary start times, their absolute fitted phases would not be directly comparable.

### Why phase was not accepted at 100 Hz

The 100 Hz gain magnitude became reasonably repeatable, but CH2 phase changed noticeably between shorter blocks and repeated runs. When the coherent output is only a few millivolts inside much larger residual variation, small noise changes can rotate the fitted phasor substantially. Therefore the project accepted the practical 100 Hz magnitude baseline but did not accept precision phase.

---

## 5. What a spectral component is

A time-domain waveform tells us voltage versus time. Spectral analysis asks a different question:

> How much of this waveform exists at each frequency?

A Fourier transform / discrete Fourier transform represents the record as a sum of sinusoidal components at different frequencies.

For a sampled record, each analyzed frequency has a complex spectral coefficient:

`X(f) = Re{X(f)} + j*Im{X(f)}`

This coefficient contains both:

- magnitude at that frequency;
- phase at that frequency.

A **spectral component at 100 Hz** therefore means the part of the measured waveform associated with a sinusoid at 100 Hz.

A clean 100 Hz sine ideally creates a strong spectral line at 100 Hz. Noise produces energy over many frequencies. Distortion creates harmonics such as 200 Hz, 300 Hz, etc.

### Relation to the coherent sine fit

The known-frequency least-squares fit and a Fourier component at the same frequency are closely related. Both project the waveform onto sine and cosine basis functions at that frequency.

The least-squares form is convenient in this project because:

- the exact commanded test frequency is already known;
- DC can be included explicitly;
- amplitude and phase are obtained directly;
- the complete spectrum does not have to be interpreted merely to extract one known component.

The FFT/DFT is useful when we want to inspect the surrounding spectrum, harmonics, interference, or local noise floor.

---

## 6. Spectral leakage and frequency bins

A finite record does not contain an infinite-duration sine. The DFT evaluates discrete frequency locations called **bins**.

Approximate bin spacing is:

`Delta_f = fs/N = 1/Trecord`

where:

- `fs` is sample rate;
- `N` is sample count;
- `Trecord` is total record duration.

If the record contains an integer number of cycles of the sine and the frequency lies exactly on a DFT bin, its energy can be concentrated strongly in one bin.

If not, its energy spreads into neighboring bins. This is called **spectral leakage**.

Window functions can reduce leakage at the cost of changing amplitude/noise bandwidth and widening the main spectral lobe. Therefore any quantitative spectrum calculation must state or control the window and amplitude correction if precision is required.

---

## 7. What neighboring spectral noise means

Suppose the wanted signal is at 100 Hz. We inspect spectral amplitudes in frequencies near 100 Hz but exclude the 100 Hz target itself.

Those nearby components estimate the local spectral background around the signal.

In the Stage B analysis, a robust local indicator used was the **median amplitude of neighboring spectral components** in a local frequency region around the target, excluding the target component itself.

Why the median rather than the maximum?

- one accidental interferer or spike can dominate the maximum;
- the median better represents the typical local background level.

This local spectral background is what was informally called **neighboring spectral noise**.

It should not be confused with residual RMS:

- residual RMS measures the total time-domain RMS of everything left after the fit;
- neighboring spectral noise estimates typical frequency-domain amplitude near the target frequency.

A waveform can have large broadband residual RMS but still have a clearly identifiable narrow coherent line at 100 Hz.

---

## 8. How a spectral component is compared in dB

For voltage/current/amplitude ratios:

`dB = 20*log10(A2/A1)`

For power ratios:

`dB = 10*log10(P2/P1)`

The factor 20 appears for voltage/current amplitudes because, for fixed impedance, power is proportional to amplitude squared.

### A. Target component versus neighboring spectral background

If:

`Vtarget = amplitude of 100 Hz component`

`Vnoise = median neighboring spectral amplitude`

then:

`contrast_dB = 20*log10(Vtarget/Vnoise)`

Examples:

- `0 dB` means equal amplitudes;
- `+6.02 dB` means target amplitude is about 2 times the reference;
- `+20 dB` means about 10 times;
- a negative result means the target amplitude is smaller than the reference level.

A result such as `+9.9 dB` means the coherent target amplitude is about `10^(9.9/20) ~= 3.1` times the local median spectral amplitude.

### B. Frequency-response normalization

For the future FILTER sweep, the magnitude at frequency `f` can be normalized to the accepted 100 Hz baseline:

`Hnorm(f) = G(f)/G(100 Hz)`

then:

`H_dB(f) = 20*log10(G(f)/G(100 Hz))`

Examples:

- `0 dB`: same amplitude gain as the baseline;
- `-3.01 dB`: amplitude ratio about 0.707;
- `-6.02 dB`: amplitude ratio about 0.5;
- `-20 dB`: amplitude ratio 0.1.

These are two different uses of dB:

1. signal-versus-local-noise contrast;
2. normalized transfer magnitude versus baseline.

They must not be mixed.

---

## 9. What four independent five-cycle sections meant

The early 100 Hz record contained about 20 cycles.

To test repeatability, the record was divided into four contiguous, non-overlapping sections:

- section 1: cycles 1–5;
- section 2: cycles 6–10;
- section 3: cycles 11–15;
- section 4: cycles 16–20.

Each section was fitted separately using the same known-frequency sine/cosine model.

For every section we recalculated:

- CH1 coherent amplitude;
- CH2 coherent amplitude;
- gain `VOUT/I`;
- phase difference.

If the measurement is robust, these values should remain reasonably similar from block to block.

If gain and phase jump strongly between five-cycle blocks, the full-record result may be strongly dependent on averaging noise rather than being a stable short-term measurement.

The word **independent** here means separate non-overlapping data blocks. It does not prove perfect statistical independence; slowly varying or correlated noise can influence multiple blocks.

Later, when the record was extended to about 100 cycles, much longer blocks such as 50-cycle halves became significantly more stable. That was evidence that longer coherent averaging improves the estimate.

---

## 10. What driver validation means in this project

The MCP6022 circuit is not the sensor under test. It is the temporary signal generator/level-shifting driver used to create positive current through the ACS724.

Before interpreting an ACS724 VIOUT waveform, the project temporarily measures:

- CH1 = RREF voltage/current reference;
- CH2 = MCP6022 pin 1 driver output.

The driver-validation check asks:

1. Is the intended frequency present?
2. Is the driver amplitude approximately as expected?
3. Is the waveform sinusoidal rather than visibly distorted?
4. Is its DC center where expected?
5. Does the output remain away from the supply rails?
6. Does RREF confirm that primary current remains positive throughout the cycle?
7. Does the load current scale sensibly when stimulus amplitude changes?

Only after these conditions are satisfied is CH2 moved from MCP6022 pin 1 to ACS724 VIOUT.

This prevents attributing source/driver failure to sensor behavior.

---

## 11. What clipping is

Clipping occurs when a circuit or measurement system cannot reproduce the requested waveform beyond some limit.

For example, if an amplifier powered from 0 V and 5 V is commanded to produce a sine that would mathematically require -0.5 V or 5.5 V, the real output cannot follow that request. Peaks flatten near the achievable limits.

Conceptually:

ideal sine:

`... smooth rounded peak ...`

clipped sine:

`... flat-topped peak ...`

Clipping can happen in several places:

- op-amp output approaching its supply/output-swing limit;
- generator output limit;
- ADC input range;
- oscilloscope vertical acquisition range;
- another circuit element saturating.

Why clipping is dangerous for transfer measurements:

- amplitude is no longer linearly related to input;
- strong harmonics are created;
- phase can shift;
- the current waveform may no longer be sinusoidal;
- fitted fundamental magnitude can become misleading.

This is why we explicitly validated the 2.00 Vpp stimulus at MCP6022 pin 1 before using it for the ACS724 measurement.

---

## 12. Electrical feedthrough and crosstalk

The intended signal path is:

`AFG -> MCP6022 -> primary current -> ACS724 Hall response -> VIOUT`

But an unwanted signal can reach VIOUT through another path.

Examples include:

- capacitive coupling between nearby wires/breadboard rows;
- shared-ground impedance;
- supply-rail coupling;
- coupling through probe leads;
- electromagnetic coupling;
- coupling internal to measurement equipment;
- direct circuit crosstalk between driver and sensor-output wiring.

This unwanted path is called **feedthrough** or **crosstalk**.

The danger is that a 100 Hz signal at VIOUT might look like a real Hall-current response even if no primary current is flowing.

### Control experiment used in the project

The primary-current path was opened by disconnecting the 220 ohm resistor from ACS724 IP+ while keeping the AFG/MCP6022 stimulus running.

This removes the intended Hall-current mechanism while preserving much of the same electrical environment.

A proper control then used:

- CH1 = MCP6022 pin 1 as a direct reference to the still-running stimulus;
- CH2 = ACS724 VIOUT;
- primary path open.

If a stable coherent 100 Hz VIOUT component with repeatable phase remains, that is evidence of feedthrough/crosstalk.

In the documented 100 Hz control, no stable coherent feedthrough strong enough to explain the current-on response was demonstrated.

---

## 13. What a phasor is

A phasor is a compact complex-number representation of a sinusoid at one fixed frequency.

For:

`v(t) = Vpk*sin(omega*t + phi)`

we can represent the sinusoidal component as:

`Vphasor = Vpk * exp(j*phi)`

or equivalently:

`Vphasor = Vpk*(cos(phi) + j*sin(phi))`

The phasor therefore contains both:

- amplitude `Vpk`;
- phase `phi`.

It can be pictured as an arrow in the complex plane:

- arrow length = amplitude;
- arrow angle = phase.

### Why phasors matter for feedthrough subtraction

Suppose the measured output contains both true sensor response and unwanted feedthrough:

`Vmeasured = Vsensor + Vfeedthrough`

At one frequency this is a **vector/complex addition**, not merely addition of magnitudes.

Therefore:

`Vsensor = Vmeasured - Vfeedthrough`

must be performed as phasor subtraction.

It is generally wrong to calculate:

`|Vsensor| = |Vmeasured| - |Vfeedthrough|`

unless both happen to have exactly the same phase.

### Example

Suppose:

`Vmeasured = 6 mV at 0 deg`

`Vfeedthrough = 1 mV at +90 deg`

As complex values:

`Vmeasured = 6 + j0 mV`

`Vfeedthrough = 0 + j1 mV`

therefore:

`Vsensor = 6 - j1 mV`

Its magnitude is:

`|Vsensor| = sqrt(6^2 + 1^2) = 6.083 mV`

and its phase is approximately:

`atan2(-1,6) = -9.46 deg`

Simply subtracting magnitudes would give `5 mV`, which is wrong.

This is why the project did not blindly subtract the amplitude of the first open-primary VIOUT control from the current-on result.

---

## 14. Connection between fitted coefficients and phasors

From the model:

`v(t) = V0 + A*sin(omega*t) + B*cos(omega*t)`

we already calculated:

`Vpk = sqrt(A^2 + B^2)`

`phi = atan2(B,A)`

Therefore the fitted sine/cosine coefficients directly define a phasor.

Conceptually:

`Vphasor = Vpk * exp(j*phi)`

This is why coherent fitting gives both transfer magnitude and transfer phase.

For two synchronized channels:

`H(f) = Vout_phasor / Iin_phasor`

The magnitude is:

`|H| = |Vout| / |Iin|`

and phase is:

`angle(H) = phi_out - phi_in`

For CH1 measured across RREF:

`Iin_phasor = Vref_phasor / RREF`

because a pure resistor does not add ideal phase shift between its voltage and current.

---

## 15. Residual RMS versus spectral noise versus coherent component

These three quantities answer different questions.

### Coherent component

> How large is the sine specifically at the commanded test frequency?

Example unit: `mVpp at 100 Hz`.

### Residual RMS

> After removing DC and the fitted target-frequency sinusoid, how large is everything else in the time record in RMS terms?

Example unit: `mV RMS`.

### Neighboring spectral noise/background

> Around the target frequency, how large are typical nearby frequency-domain components compared with the target spectral line?

Example unit: `mVpp-equivalent spectral amplitude` or a target/background ratio in dB, depending on the analysis normalization.

None of these should be substituted blindly for another.

---

## 16. Why a coherent signal can be smaller than residual RMS and still be measurable

This was important for ACS724 VIOUT.

Imagine a 6 mVpp sine buried inside broadband random variation with about 30 mV RMS total residual magnitude.

The random/noisy part changes sign and phase unpredictably from cycle to cycle.

The true 100 Hz sine repeats at exactly the same frequency and phase relationship.

When many cycles are analyzed coherently, the repeating component adds consistently while incoherent noise tends to average down.

This is why extending the record from about 20 cycles to about 100 cycles improved the stability of the 100 Hz gain estimate without increasing the electrical stimulus.

This is also why raw oscilloscope peak-to-peak values were unsuitable: raw peaks respond strongly to broadband spikes, while coherent fitting asks only for the repeatable component at the commanded frequency.

---

## 17. Why block-to-block stability is important

A full-record fit always produces a number. That alone does not prove the number is trustworthy.

A useful robustness check is to divide the record into separate blocks and repeat the calculation.

If the result is real and sufficiently above the uncertainty/noise environment, then:

- gain should remain reasonably consistent;
- phase should remain reasonably consistent;
- the current reference should remain stable.

Large block-to-block jumps indicate that:

- the record may be too short;
- SNR may be insufficient;
- interference may be dominating;
- phase may not yet be measurable precisely;
- the stimulus or measurement may not be stationary.

This is why the project did not immediately accept early full-record gain numbers even when a numerical value could be calculated.

---

## 18. Practical interpretation hierarchy for this project

When judging each future frequency point, use this order:

1. **Driver validity** — correct node, correct frequency, no visible clipping, sensible amplitude/headroom.
2. **Current validity** — CH1/RREF clean enough, sufficient sampling/resolution, primary current stays within the valid positive range.
3. **Synchronized acquisition** — CH1 and CH2 from the same frozen record.
4. **Coherent component** — fit the exact commanded frequency.
5. **Fit quality / residuals** — inspect `R^2`, residual RMS, distortion and harmonics.
6. **Spectral context** — verify the target line stands sensibly above neighboring spectral background and check for unexpected harmonics/interference.
7. **Repeatability** — compare blocks and/or repeated acquisitions.
8. **Controls** — when suspicious, remove the intended physical mechanism and test for feedthrough/crosstalk.
9. **Only then interpret transfer magnitude/phase**.

A mathematically calculated gain is not automatically an accepted engineering measurement.

---

## 19. Compact formula reference

Known-frequency fit:

`v(t) = V0 + A*sin(2*pi*f*t) + B*cos(2*pi*f*t)`

Peak amplitude:

`Vpk = sqrt(A^2 + B^2)`

Peak-to-peak amplitude:

`Vpp = 2*Vpk`

Phase:

`phi = atan2(B,A)`

Residual:

`r_i = y_i - yhat_i`

Residual RMS:

`RMSres = sqrt(sum(r_i^2)/N)`

Coefficient of determination:

`R^2 = 1 - sum(r_i^2)/sum((y_i-ybar)^2)`

Current from RREF:

`Iphasor = V_RREF_phasor / RREF`

Transfer phasor:

`H(f) = VOUT_phasor / I_phasor`

Transfer magnitude:

`|H| = |VOUT|/|I|`

Transfer phase:

`angle(H) = phi_VOUT - phi_I`

Amplitude ratio in dB:

`20*log10(A2/A1)`

Normalized frequency response:

`H_dB(f) = 20*log10(G(f)/G(100 Hz))`

Phasor addition/subtraction:

`Vmeasured = Vsensor + Vfeedthrough`

`Vsensor = Vmeasured - Vfeedthrough`

---

## 20. Engineering status after this study record

This document explains the analysis concepts only. The current Stage B engineering state remains:

- accepted practical 100 Hz normalized-sweep magnitude baseline: `G100 = 0.8792 V/A`;
- prior independent DC calibration remains a separate result and is not replaced;
- precision 100 Hz phase remains unaccepted;
- no stable coherent feedthrough sufficient to explain the 100 Hz current-on response was demonstrated in the proper open-primary control;
- first 1 kHz files `021`/`022` remain quarantined/non-accepted because of inadequate sampling and distorted CH1 capture;
- no external ACS724 FILTER capacitor has been approved yet.

The next engineering work after this study gate is to re-establish a valid 1 kHz acquisition with adequate time resolution and validated driver/current waveforms before interpreting any 1 kHz transfer result.

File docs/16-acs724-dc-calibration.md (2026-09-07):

# 16 — ACS724 DC Calibration

**Status:** Stage B bench characterization result  
**Date:** 2026-09-07  
**Applies to:** Pololu #4048 ACS724LLCTR-05AU, Arduino-powered signal side, bench resistive current load

## 1. Purpose

The purpose of this experiment was to verify the ACS724 current-sensor DC transfer behavior with a known, stable current before using the sensor for dynamic motor-current measurements.

The experiment was designed to answer four questions:

1. Does the high-current path through the ACS724 conduct correctly?
2. Does `VOUT` increase monotonically with current in the expected current direction?
3. What zero-current offset is observed in the present bench setup?
4. What practical sensitivity is obtained from measured data?

This test intentionally used a resistor load instead of the motor so that current could be predicted directly from Ohm's law and checked against the bench-PSU indication.

---

## 2. Relevant hardware

- current sensor: Pololu #4048 ACS724LLCTR-05AU, unidirectional 0–5 A carrier
- controller / sensor supply: Arduino UNO R4 WiFi
- bench PSU: Jesverty SPS-3010V
- multimeter: VC830L
- load resistors: BOJACK 56 Ω, 1%, 1/4 W metal-film resistors
- solderless breadboard

The ACS724 signal side was powered from the Arduino:

`Arduino 5 V → ACS724 VCC`

`Arduino GND → ACS724 GND`

The multimeter measured:

`red probe → ACS724 OUT`

`black probe → ACS724 GND`

The high-current path was:

`PSU+ → ACS724 IP+ → ACS724 IP− → resistor load → PSU−`

The motor was removed from the calibration circuit.

---

## 3. Pre-test troubleshooting and safety findings

Before this calibration, Windows repeatedly reported a USB-port power-surge warning while the Arduino was connected with external breadboard wiring.

The fault-isolation sequence was:

1. disconnect Arduino USB
2. remove all external Arduino wiring
3. reconnect the bare Arduino only
4. confirm that the USB warning disappeared
5. verify breadboard continuity with the circuit unpowered
6. verify power-rail isolation
7. verify ACS724 `VCC–GND`, `OUT–GND`, and `OUT–VCC` had no direct continuity short
8. rebuild the sensor wiring one connection at a time

The warning did not recur after the circuit was rebuilt correctly.

Engineering conclusion:

**The USB overcurrent warning was associated with the external wiring state, not with normal operation of the bare Arduino.**

This established a Stage B bench rule:

**When a suspected short or overcurrent event occurs, isolate the source while unpowered and rebuild one verified connection at a time.**

---

## 4. Breadboard verification

The breadboard topology was verified experimentally using the multimeter continuity function.

Observed:

- `f2 ↔ j2`: continuity present
- `f2 ↔ f3`: no continuity
- same positive power rail, separated points: continuity present
- same negative power rail, separated points: continuity present
- positive rail ↔ negative rail: no continuity

This confirmed that the numbered `f–j` groups were internally common by row and that adjacent rows and opposite rails were isolated.

The ACS724 logic pins were installed as:

- `j1` = OUT
- `j2` = VCC
- `j3` = GND

With the ACS724 inserted, the same no-short behavior remained between its logic pins.

---

## 5. Sensor-side preliminary measurements

With the ACS724 powered from the Arduino and no measurement current applied:

- measured `VCC–GND`: **4.65 V**
- measured `OUT–GND`: approximately **0.48–0.49 V** during initial checks

The current project rule remains that these are raw bench readings. The earlier PSU-versus-multimeter comparison showed an indication discrepancy near 5 V, but no formal multimeter calibration has been performed.

Therefore the 4.65 V reading shall not be silently corrected.

---

## 6. Current-direction check

With the motor initially used as a small load, reversing the ACS724 high-current path changed the sensor output direction.

One observed reversed-direction condition at approximately 35 mA produced:

`VOUT ≈ 0.43 V`

Restoring the intended current direction returned the output toward the zero-current level.

This confirmed that the sensor was responding to current direction and reinforced the intended wiring:

`PSU+ → IP+ → IP− → load → PSU−`

Because this ACS724 variant is unidirectional, the calibration was performed only in the direction that increases `VOUT` above the zero-current offset.

---

## 7. Resistive calibration load design

Three 56 Ω, 1/4 W resistors were first placed in parallel on the breadboard.

Measured equivalent resistance:

`R_eq,3 = 18.8 Ω`

Ideal value:

`56 Ω / 3 = 18.67 Ω`

The measured value is consistent with the resistor values and meter resolution.

At 3.00 V, predicted current for the three-resistor load is:

`I = V / R = 3.00 / 18.8 = 0.1596 A`

The PSU indicated approximately:

`I = 0.157–0.158 A`

which closely agrees with the Ohm's-law prediction.

For one 56 Ω branch at 3.00 V:

`I_branch = 3.00 / 56 = 53.6 mA`

and resistor dissipation is:

`P_branch = V² / R = 3.00² / 56 = 0.161 W`

Each resistor is rated at 0.25 W, therefore:

`0.161 W < 0.25 W`

The individual resistors were operated below their nominal power rating, although noticeable warming is still possible and long unattended operation is not intended.

---

## 8. Raw calibration data

The PSU was held at **3.00 V**. Current was changed by using 0 to 4 identical 56 Ω resistors in parallel.

| Parallel 56 Ω resistors | PSU current (A) | PSU power (W) | ACS724 VOUT (V) |
|---:|---:|---:|---:|
| 0 | 0.000 | 0.000 | 0.469 |
| 1 | 0.052 | 0.156 | 0.508 |
| 2 | 0.106 | 0.318 | 0.548 |
| 3 | 0.157 | 0.468 | 0.586 |
| 4 | 0.208 | 0.624 | 0.624 |

The PSU powers above are the observed display values recorded during the test.

The measured current progression is close to the expected approximately 53.6 mA increment per added 56 Ω branch.

---

## 9. Linear fit

The measured data were fitted with the first-order model:

`VOUT = V0 + S·I`

Least-squares fit result:

`VOUT = 0.46910 + 0.74472·I`

where:

- `VOUT` is in volts
- `I` is in amperes
- fitted zero-current intercept `V0 = 0.46910 V`
- fitted sensitivity `S = 0.74472 V/A = 744.72 mV/A`

Coefficient of determination:

`R² = 0.999997`

This demonstrates very strong linearity over the tested range from 0 A to 0.208 A.

The inverse conversion for this measured bench condition is:

`I = (VOUT - 0.46910) / 0.74472`

This equation is a **bench calibration result for the present sensor/supply/instrument condition**, not yet a universal production calibration constant.

---

## 10. Residuals from the fitted line

| Current (A) | Measured VOUT (V) | Fit VOUT (V) | Residual (mV) |
|---:|---:|---:|---:|
| 0.000 | 0.469 | 0.469103 | -0.103 |
| 0.052 | 0.508 | 0.507828 | +0.172 |
| 0.106 | 0.548 | 0.548043 | -0.043 |
| 0.157 | 0.586 | 0.586023 | -0.023 |
| 0.208 | 0.624 | 0.624004 | -0.004 |

The residuals are much smaller than 1 mV. They should not be overinterpreted as sensor accuracy because the multimeter resolution, PSU indication accuracy, resistor tolerance, sensor supply uncertainty, temperature, and other bench uncertainties have not yet been combined into a formal calibration uncertainty budget.

The residuals do, however, show that the measured points are extremely close to a straight line.

---

## 11. Calibration graph

ACS724 DC calibration

The graph plots the five measured points and the least-squares linear fit.

---

## 12. Comparison with nominal sensitivity

The nominal sensitivity used previously for prediction was approximately:

`S_nom ≈ 0.8 V/A`

The measured slope was:

`S_meas = 0.74472 V/A`

Relative difference from the simple nominal value:

`(0.74472 - 0.8) / 0.8 × 100% ≈ -6.9%`

This difference must not yet be classified as a sensor fault.

Possible contributors include:

- actual sensor VCC differing from the 5 V nominal condition
- sensor gain tolerance
- multimeter indication error / resolution
- PSU current-indication accuracy
- resistor tolerance and temperature rise
- temperature dependence of sensor offset and sensitivity
- contact and wiring resistance

A later higher-quality calibration should measure the sensor supply and output with a better-characterized reference instrument and should include uncertainty explicitly.

---

## 13. Important measurement mistake captured during the experiment

At one point, the multimeter was accidentally connected between `OUT` and `VCC` instead of between `OUT` and `GND`.

The meter displayed approximately:

`-4.07 V`

This was not a negative ACS724 output voltage. It was the voltage difference between the two probe locations.

For example, with approximately:

`VOUT ≈ 0.57–0.59 V`

and

`VCC ≈ 4.65 V`

then:

`VOUT - VCC ≈ -4.06 to -4.08 V`

which explains the observed reading.

Engineering lesson:

**A voltmeter measures potential difference between its red and black probes. A statement such as “the voltage at OUT” is incomplete unless the reference node is also stated.**

For this project, sensor-output measurements shall be written explicitly as `VOUT-to-GND` unless another reference is intentionally used.

---

## 14. PSU current-limit lesson

The calibration was performed with a PSU current limit of approximately **0.5 A**.

The maximum measured load current was:

`0.208 A`

which remained below the configured limit.

The PSU current limit is a protection mechanism: if the connected load attempts to draw more current than the configured limit, the supply should leave normal constant-voltage operation and reduce output voltage as required to limit current.

However:

**Current limiting is not a substitute for correct wiring.**

Short circuits or incorrect connections can still create local heating, connector stress, component damage, or USB-port protection events. Wiring verification remains mandatory before power is applied.

---

## 15. Engineering conclusions

The experiment establishes the following Stage B results:

1. The ACS724 signal side can be powered successfully from the Arduino in the present bench arrangement.
2. The high-current path operates correctly in the intended direction.
3. The sensor output increases monotonically with current over the tested 0–208 mA range.
4. The measured zero-current intercept is approximately **0.469 V** for this calibration run.
5. The measured DC sensitivity is approximately **0.745 V/A**.
6. The transfer is extremely linear over the tested range, with `R² ≈ 0.999997`.
7. The resistor-load current agrees closely with Ohm's-law prediction and PSU indication.
8. The ACS724 is therefore suitable to proceed to controlled motor-current measurement and later dynamic waveform capture.

This is the first deliberate bench calibration of the current-sensing chain in Stage B.

---

## 16. Limitations

This result does **not** yet establish:

- production calibration accuracy
- full 0–5 A behavior
- dynamic bandwidth
- startup-current peak accuracy
- temperature drift
- long-term offset stability
- Arduino ADC conversion accuracy
- total system measurement uncertainty
- behavior after analog filtering

The tested current range was only 0–0.208 A.

The present fit should therefore be treated as a verified low-current bench calibration, not as final product calibration.

---

## 17. Next actions

Recommended next sequence:

1. repeat zero-current reading before and after the next test to observe short-term offset drift
2. route the motor current through the ACS724 in the validated direction
3. record simultaneous PSU current and ACS724 DC output at steady motor operation
4. convert sensor output to current using the measured calibration equation and compare with PSU indication
5. connect the oscilloscope to `ACS724 OUT-to-GND`
6. capture motor startup current as a time-domain waveform
7. separate true motor-current dynamics from PSU turn-on behavior already identified in B-005
8. later introduce Arduino ADC acquisition only after the analog sensor behavior is understood

The immediate next engineering objective is therefore **validated motor-current measurement using the now-calibrated ACS724 chain**.

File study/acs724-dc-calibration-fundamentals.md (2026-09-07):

# ACS724 DC Calibration Fundamentals

This note explains the learning behind the Stage B ACS724 resistive-load calibration. The formal engineering result is recorded in `docs/16-acs724-dc-calibration.md`.

## Why use resistors instead of the motor first?

A motor is a dynamic electromechanical load. Its current depends on winding resistance, back-EMF, speed, mechanical load, commutation, startup state, and PSU behavior.

A resistor is much simpler:

`I = V / R`

If voltage and resistance are known, current can be predicted before the circuit is powered. This makes a resistor load useful for checking whether the current sensor behaves correctly.

## Why three 56 Ω resistors in parallel?

One 56 Ω resistor at 3 V draws approximately:

`I = 3 / 56 = 53.6 mA`

Three identical resistors in parallel have:

`R_eq = 56 / 3 = 18.67 Ω`

so total current becomes approximately:

`I = 3 / 18.67 = 161 mA`

The sensor output shift becomes easier to observe because the ACS724 output change is approximately proportional to current.

The important idea is:

**More parallel branches reduce equivalent resistance, therefore the source supplies more total current.**

This is different from series connection, where equivalent resistance increases.

## Why not use one low-value resistor?

A single low-value resistor may dissipate too much power.

For a resistor:

`P = V² / R`

For 15 Ω at 3 V:

`P = 9 / 15 = 0.6 W`

A 1/4 W resistor would be overloaded.

Using several higher-value resistors in parallel shares the total power among branches.

For each 56 Ω resistor at 3 V:

`P = 9 / 56 = 0.161 W`

which is below the 0.25 W resistor rating.

## Why does each parallel resistor see the full 3 V?

All three resistor left ends are connected to one common node and all three right ends are connected to the other common node.

Therefore each resistor is connected across the same two electrical potentials.

That means every branch sees the same voltage:

`V1 = V2 = V3 = 3 V`

The branch currents add:

`I_total = I1 + I2 + I3`

For identical resistors the currents are approximately equal.

## Why did the measured resistance equal 18.8 Ω?

Three ideal 56 Ω resistors in parallel give:

`56 / 3 = 18.67 Ω`

The measured network resistance was 18.8 Ω.

The difference can come from resistor tolerance, multimeter accuracy, probe/contact resistance, and rounding. The measured result is very close to expectation and confirmed that all three resistors were actually connected in parallel.

## Understanding the ACS724 transfer

A simplified current-sensor model is:

`VOUT = V0 + S·I`

where:

- `V0` = zero-current output voltage
- `S` = sensitivity in volts per ampere
- `I` = measured current

If current increases and the sensor is used in its intended direction, `VOUT` should increase approximately linearly.

For this calibration the measured fit was:

`VOUT = 0.46910 + 0.74472·I`

Therefore:

- measured zero-current intercept ≈ 0.469 V
- measured sensitivity ≈ 0.745 V/A

To convert voltage back to current:

`I = (VOUT - 0.46910) / 0.74472`

## What does sensitivity mean?

Sensitivity tells us how much sensor output voltage changes for each ampere of current.

For example:

`S = 0.745 V/A`

means that an increase of 1 A would ideally increase the sensor output by about 0.745 V under the same calibration condition.

For 0.1 A:

`ΔV ≈ 0.745 × 0.1 = 0.0745 V`

or about 74.5 mV.

## What does R² mean here?

The measured calibration gave:

`R² ≈ 0.999997`

R² describes how closely the measured data follow the fitted straight-line model.

A value very close to 1 means the five measured points lie extremely close to a straight line over the tested current range.

It does **not** mean the sensor is 99.9997% accurate.

Linearity and absolute accuracy are different concepts.

The entire line could, for example, have the wrong slope but still have an R² extremely close to 1.

## Why was the measured sensitivity lower than the nominal 0.8 V/A?

The nominal value was used as a design prediction, but the bench fit gave approximately 0.745 V/A.

That difference can come from several sources:

- supply voltage not exactly 5 V
- sensor gain tolerance
- sensor temperature
- PSU current indication uncertainty
- multimeter voltage indication uncertainty
- resistor tolerance and heating
- contact/wiring effects

One calibration run cannot identify the contribution of each source.
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

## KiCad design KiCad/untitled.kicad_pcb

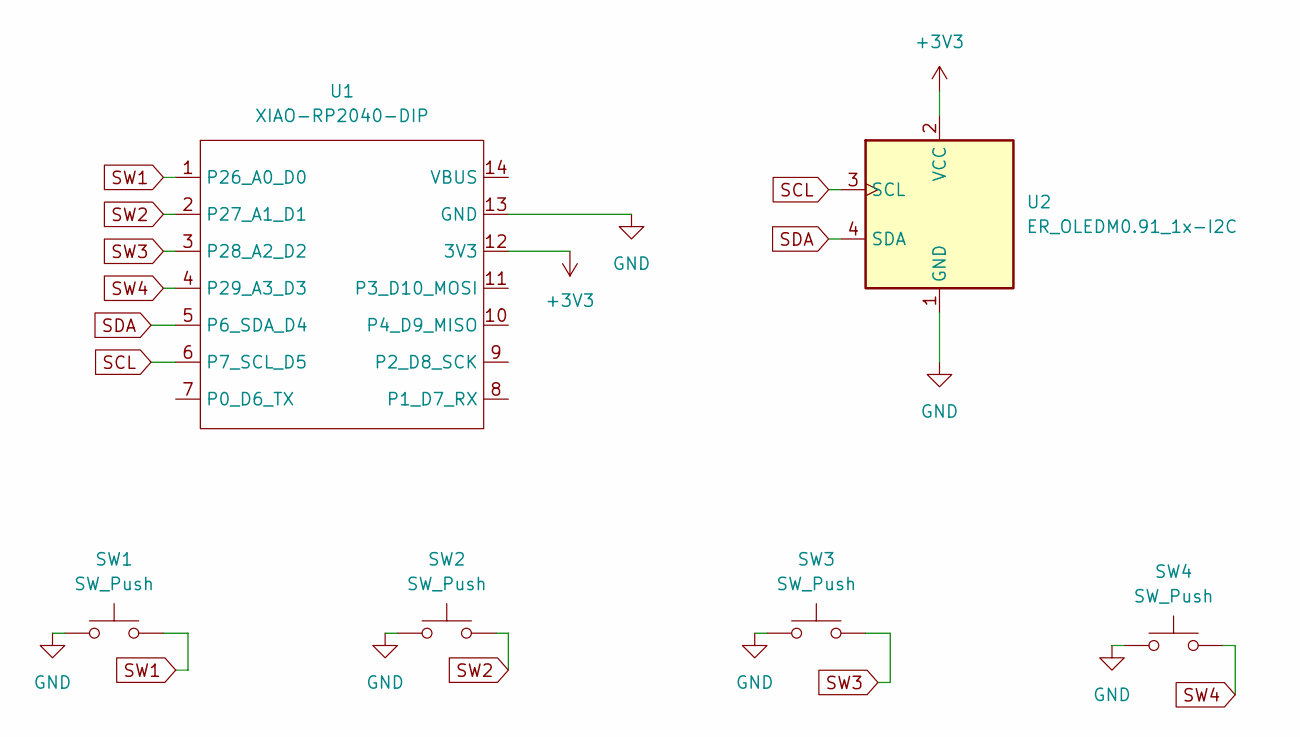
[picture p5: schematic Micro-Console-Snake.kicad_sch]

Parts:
SW1, SW2, SW3, SW4: SW_Push; SW_PUSH_6mm
U1: XIAO-RP2040-DIP; DIP-14_W7.62mm
U2: ER_OLEDM0.91_1x-I2C

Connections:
+3V3: U1.12 (3V3), U2.2 (VCC)
GND: SW1.1, SW2.1, SW3.1, SW4.1, U1.13 (GND), U2.1 (GND)
SCL: U1.6 (P7_SCL_D5), U2.3 (SCL)
SDA: U1.5 (P6_SDA_D4), U2.4 (SDA)
SW1: SW1.2, U1.1 (P26_A0_D0)
SW2: SW2.2, U1.2 (P27_A1_D1)
SW3: SW3.2, U1.3 (P28_A2_D2)
SW4: SW4.2, U1.4 (P29_A3_D3)

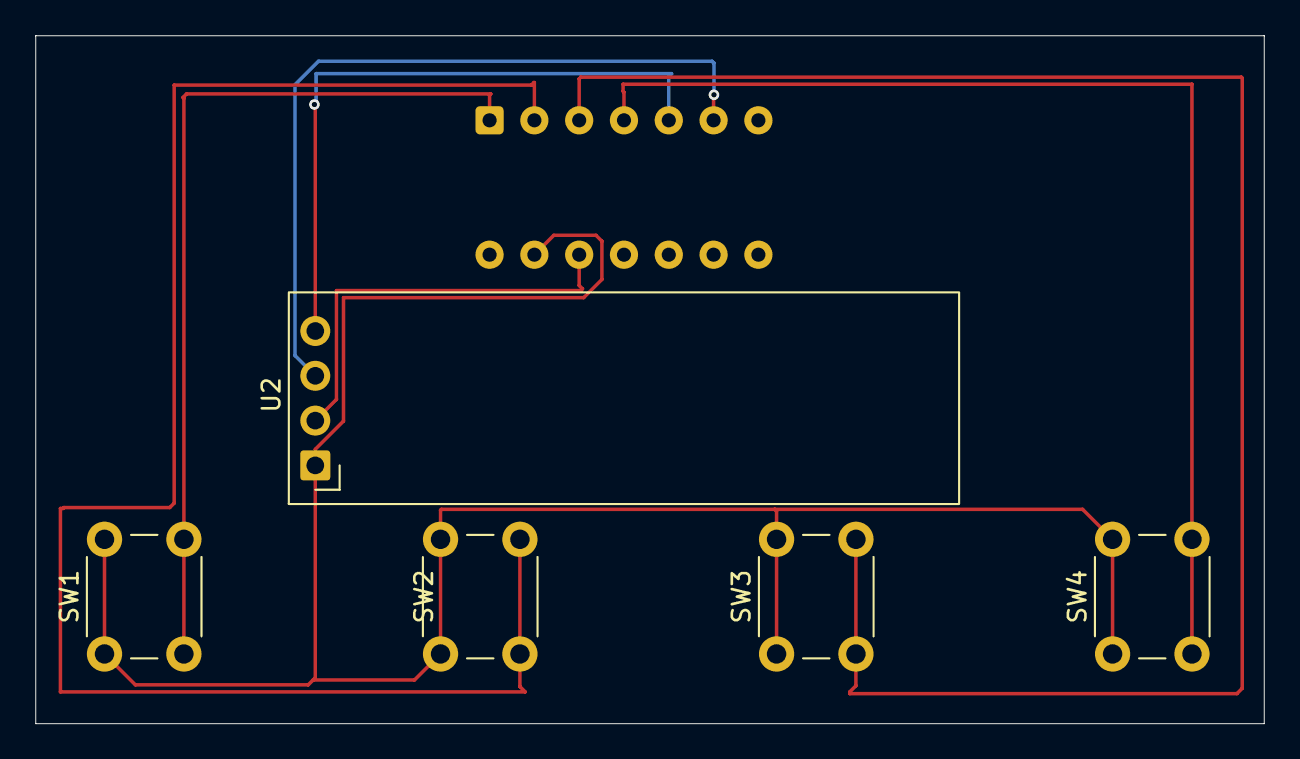
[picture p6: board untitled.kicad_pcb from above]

Board: 2 copper layers, 69.6 x 39.0 mm, 6 parts (1 on the bottom side), 8 nets.

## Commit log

2026-08-14 Phase 1 — System Requirements
2026-08-14 Accept ARCH-005 power-domain architecture
2026-08-15 Complete Phase 2 architecture and traceability
2026-08-15 Initialize Phase 3 sensor characterization record
2026-08-15 Accept SENS-001 Hall-effect current sensing principle
2026-08-16 Accept SENS-002 sensor operating range
2026-08-17 Accept SENS-004 sensor bandwidth configuration
2026-08-17 Accept SENS-005 primary current-path resistance
2026-08-17 Accept SENS-007 sensor accuracy characterization
2026-08-17 Accept SENS-008 current conversion model
2026-08-17 SENS-009 characterize sensor error categories
2026-08-17 Accept SENS-010 FILTER-pin role
2026-08-17 Document SENS-013 zero-current offset and noise test
2026-08-17 Document SENS-022 zero-current evidence record
2026-08-17 Document SENS-024 zero-current noise metric
2026-08-17 Start Phase 4 measurement-chain design
2026-08-17 Baseline Phase 5 Butterworth filter response
2026-08-17 Baseline Phase 5 filter realization
2026-08-17 Initialize Phase 6 ADC and acquisition design
2026-08-17 Baseline Phase 6 ADC resolution strategy
2026-08-17 Baseline deterministic ADC trigger architecture
2026-08-17 Baseline Phase 6 buffered sample transfer
2026-08-17 Baseline Phase 7 firmware data flow
2026-08-17 Baseline Phase 7 calibrated feature interface
2026-08-17 Baseline overload and stall diagnostic logic
2026-08-18 Initialize Phase 10 power and protection design
2026-08-18 Baseline Phase 10 separated power domains
2026-08-18 Baseline Phase 10 grounding and return strategy
2026-08-18 Initialize Phase 11 calibration and MATLAB analysis design
2026-08-18 Baseline Phase 11 linear calibration model
2026-08-18 Baseline calibration traceability architecture
2026-08-18 Complete Phase 11 calibration and healthy-reference separation
2026-08-18 Baseline actuator current-path integration
2026-08-18 Freeze Rev-1 measurement-electronics power source
2026-08-18 Baseline Phase 12 grounding and instrument connection architecture
2026-08-18 Freeze Phase 12 AFE filter component values
2026-08-18 Freeze complete AFE net-level circuit
2026-08-18 Select Rev-1 Philips Saeco 24 V brew-group gearmotor
2026-08-18 Baseline Rev-1 BOM and procurement status
2026-08-18 Freeze Rev-1 wiring and interconnect specification
2026-08-18 Baseline Rev-1 mechanical assembly constraints
2026-08-18 Freeze Rev-1 ADC interface and protection
2026-08-18 Add requirements verification traceability framework
2026-08-18 Define complete-chain calibration accuracy acceptance
2026-08-18 Define diagnostic overload and stall acceptance
2026-08-18 Define power grounding and physical integration acceptance
2026-08-18 Define verification evidence traceability acceptance
2026-08-18 Freeze authoritative Rev-1 Stage A baseline
2026-08-18 Define Stage B implementation sequence
2026-08-18 Complete Stage A design freeze and implementation handoff
2026-09-07 docs: add Stage B implementation log
2026-09-07 Document ACS724 DC calibration experiment
2026-09-07 Add ACS724 calibration graph
2026-09-07 Add ACS724 calibration study notes
2026-09-07 Index ACS724 calibration study notes
2026-09-07 Document ACS724 motor validation and noise exploration
2026-09-07 Document raw waveform export and speed-dependent motor spectrum
2026-09-07 docs: refresh README with current Stage B status
2026-09-07 docs: record ACS724 zero-current noise isolation
2026-09-08 docs: add ACS724 filter pre-build theory and predictions
2026-09-10 Stage B: document MCP6022 buffer bring-up and theory
2026-09-10 Stage B: record MCP6022 channel-A unloaded dynamic validation
2026-09-10 docs: explain MCP6022 channel-A resistor network and supply bypass theory
2026-09-10 Stage B: record first positive-current 100 Hz ACS724 coherent capture
2026-09-10 Document improved-resolution 100 Hz ACS724 recapture
2026-09-10 Stage B: document stronger 100 Hz positive-current ACS724 capture
2026-09-10 Stage B: close 100 Hz positive-current ACS724 baseline
2026-09-11 Stage B: document signal-analysis study concepts
2026-09-12 Stage B: capture ACS724 test fixture in KiCad
    [actuator-health.kicad_pcb, actuator-health.kicad_sch]
2026-09-14 docs: record stable CH1 reading at 100 Hz after Sample step
2026-09-14 docs: archive 100 Hz captures and diagnose the CH1 discontinuity
    [data_27_000_CH1_avg100Hz_2pp.csv, data_27_001_CH2_avg100Hz_2pp.csv]
2026-09-14 Confirm stopped exports and estimate provisional paired sensor response
2026-09-14 Document controlled Sample vs Average-64 export retest
2026-09-14 KiCad schematic work before sync
    [RCfilter.kicad_pcb, RCfilter.kicad_sch, actuator-health.kicad_sch]
2026-09-28 Schematics update
    [actuator-health.kicad_sch]
2026-09-30 Study: document low-Q Sallen-Key capacitor behavior
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2026-09-30 Stage B: prepare schematic for AFE bring-up
    [actuator-health.kicad_sch]
2026-09-30 Stage B: implement Rev-1 AFE schematic
    [actuator-health.kicad_sch]
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2026-09-30 Stage B: record Rev-1 AFE DC bring-up gate
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2026-09-30 Evidence: correct divider diagnosis for changed power state
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2026-09-30 Evidence: identify missing AFG-to-capacitor-bank connection
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2026-10-05 Evidence: localize 5 kHz attenuation to low-Q stage
2026-10-05 Evidence: mark invalid pin-3 capture after stimulus loss
2026-10-05 Evidence: correct pin-3 capture cause to disconnected AFG
2026-10-05 Evidence: correct pin-3 diagnostic setup and localize passive-stage fault
2026-10-05 Evidence: localize 5 kHz fault to N2A ground pull
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2026-10-05 Evidence: retract false pin-3 conclusions after probe-placement error
2026-10-05 Schematics: add temporary AFE biased-source test fixture
    [afe-bias-test-fixture.kicad_sch]
2026-10-05 Schematics: document biased-source fixture wiring and checks
2026-10-05 Schematics fixes update
    [actuator-health.kicad_sch]
2026-10-05 Schematics merged. Unused deleted.
    [RCfilter.kicad_pcb, RCfilter.kicad_sch, actuator-health.kicad_sch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]
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2026-10-15 docs(study): explain RA4M1 ADC sampling and conversion timing
2026-10-15 docs(study): explain hardware timer and 10 us ADC trigger timing
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2026-10-15 docs(study): explain SAR binary conversion and ADC clock timing
